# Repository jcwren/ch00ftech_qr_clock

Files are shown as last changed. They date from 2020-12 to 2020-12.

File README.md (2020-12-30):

These are the source files for the ch00ftech QR clock. I put them on GitHub
since they're somewhat hard to find on the web site. Included are links to the
original pages where they came from.

All rights remain with Michael Ciuffo. His WordPress blog at
https://ch00ftech.com has been inactive since December 15, 2017, as has his
Twitter feed.

v1.1 is the original QR clock in kit form. v2.2 is the production clock
that was available on [Tindie](https://www.tindie.com/stores/ch00ftech/)

* [Original link to v1.1 source files](https://ch00ftech.com/2012/10/27/qr-clock)
* [Original link to v2.2 source files](https://ch00ftech.com/qrclock/)
* [All QR clock related posts](https://ch00ftech.com/category/qr-clock/)

[Eagle](https://www.autodesk.com/products/eagle/overview) version 6.4 was used
for the hardware design. Eagle is at v9.6.2 at the time this README was
created. It is unknown if it can import a version that far back or not.

AVR-GCC is use to compile the firmware for the ATMega328P. It will likely
compile with more recent versions, although probably with more warnings as GCC
has improved it's detection of question expressions. It is unknown what version
was used for the original release. AVR-GCC is available
[here](https://blog.zakkemble.net/avr-gcc-builds/) for Windows, and can be
installed with HomeBrew on MacOS or apt-get (or equivalent) on Linux.

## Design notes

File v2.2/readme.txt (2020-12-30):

       _      ___   ___   __ _            _     
      | |    / _ \ / _ \ / _| |          | |    
   ___| |__ | | | | | | | |_| |_ ___  ___| |__  
  / __| '_ \| | | | | | |  _| __/ _ \/ __| '_ \ 
 | (__| | | | |_| | |_| | | | ||  __/ (__| | | |
  \___|_| |_|\___/ \___/|_|  \__\___|\___|_| |_|
                                                
QR Clock Readme v2.1 4/2/2012

By: Michael Ciuffo
ch00f@ch00ftech.com

http://ch00ftech.com/qrclock

*********************
*Package Description*
*********************

This package contains the following two folders:

--Hardware
Eagle files for schematic and PCB layout of the device along with a PNG schematic.  Digikey part numbers are included in part attributes. The symbol for D7 is backwards in the schematic.  Photodiodes should be reverse biased.

--Firmware
Firmware and Makefile for the QR clock.  Should compile with with avrdude version 5.11.1.

**********
*Versions*
**********

2.2 - Fixed a bug resulting from a misinterpretation of the QR code generation process.  After the XOR step, only the *first* zero is supposed to be removed even if more than one is there.  Modified code to only remove first zero.  This bug caused an invalid QR code with very specific inputs such as “00Y9PT0040016002”

**********
*Warnings*
**********

THIS IS NOT A TUTORIAL! These are the design files that I used to create what you see on my blog.  They are meant to be used as reference only.  If you do not understand how the project is supposed to work, do not begin working on it.  Given how haphazardly a lot of my projects are put together, in all likelihood, the designs presented herein won't actually work due to changes I made post publication.

I am a EE, not a coder.  My programming practices are questionable at best.  If you learn anything from working on this project, please don't let it be how to code like I do.

*********
*License*
*********

The contents of this package are released to you under the Creative Commons Attribution-NonCommercial 3.0 Unported license.

This means that you are free to distribute this package and edit it as you see fit.  All works based on this package must provide attribution in some form to me.  A simple link to the blog post along with a description of what you used will suffice.

You may not use this package for any commercial ventures without my consent (but I'm usually cool with it, you just have to send me an email and ask nicely).

More information here:

http://creativecommons.org/licenses/by-nc/3.0/deed.en_US

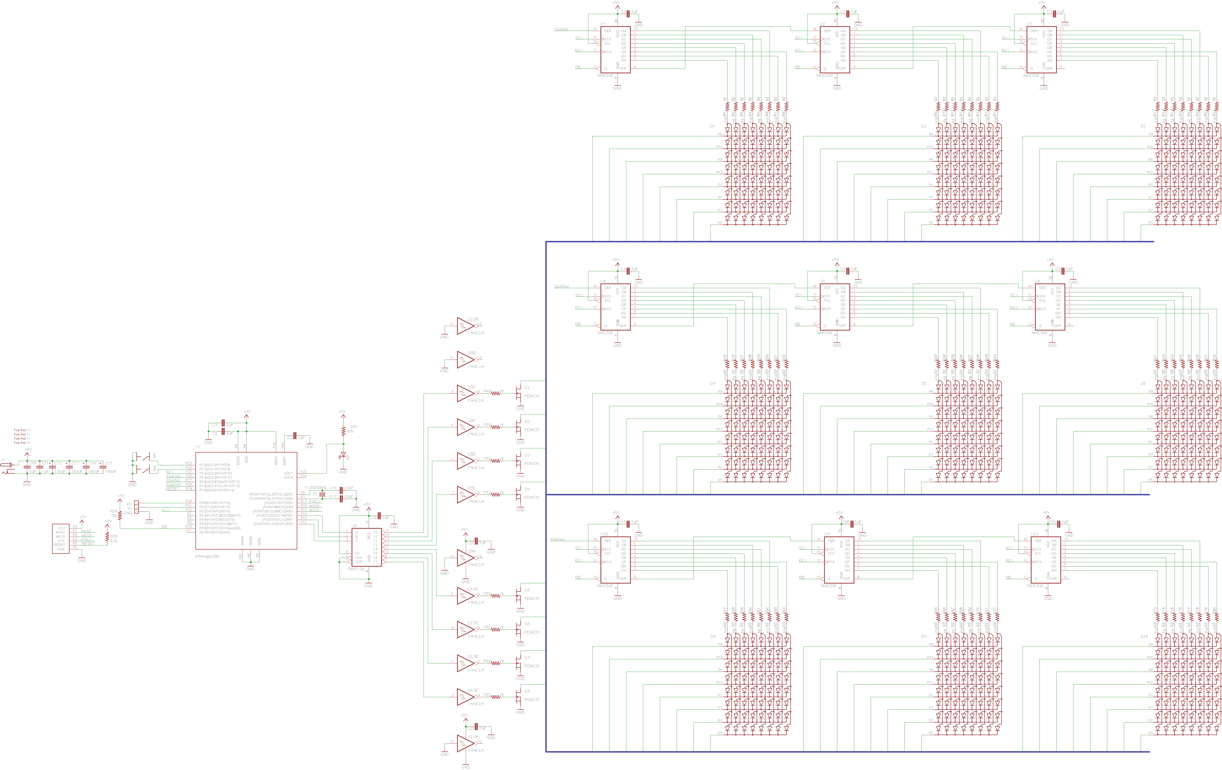
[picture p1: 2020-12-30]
v2.2/Hardware/qrclock.png

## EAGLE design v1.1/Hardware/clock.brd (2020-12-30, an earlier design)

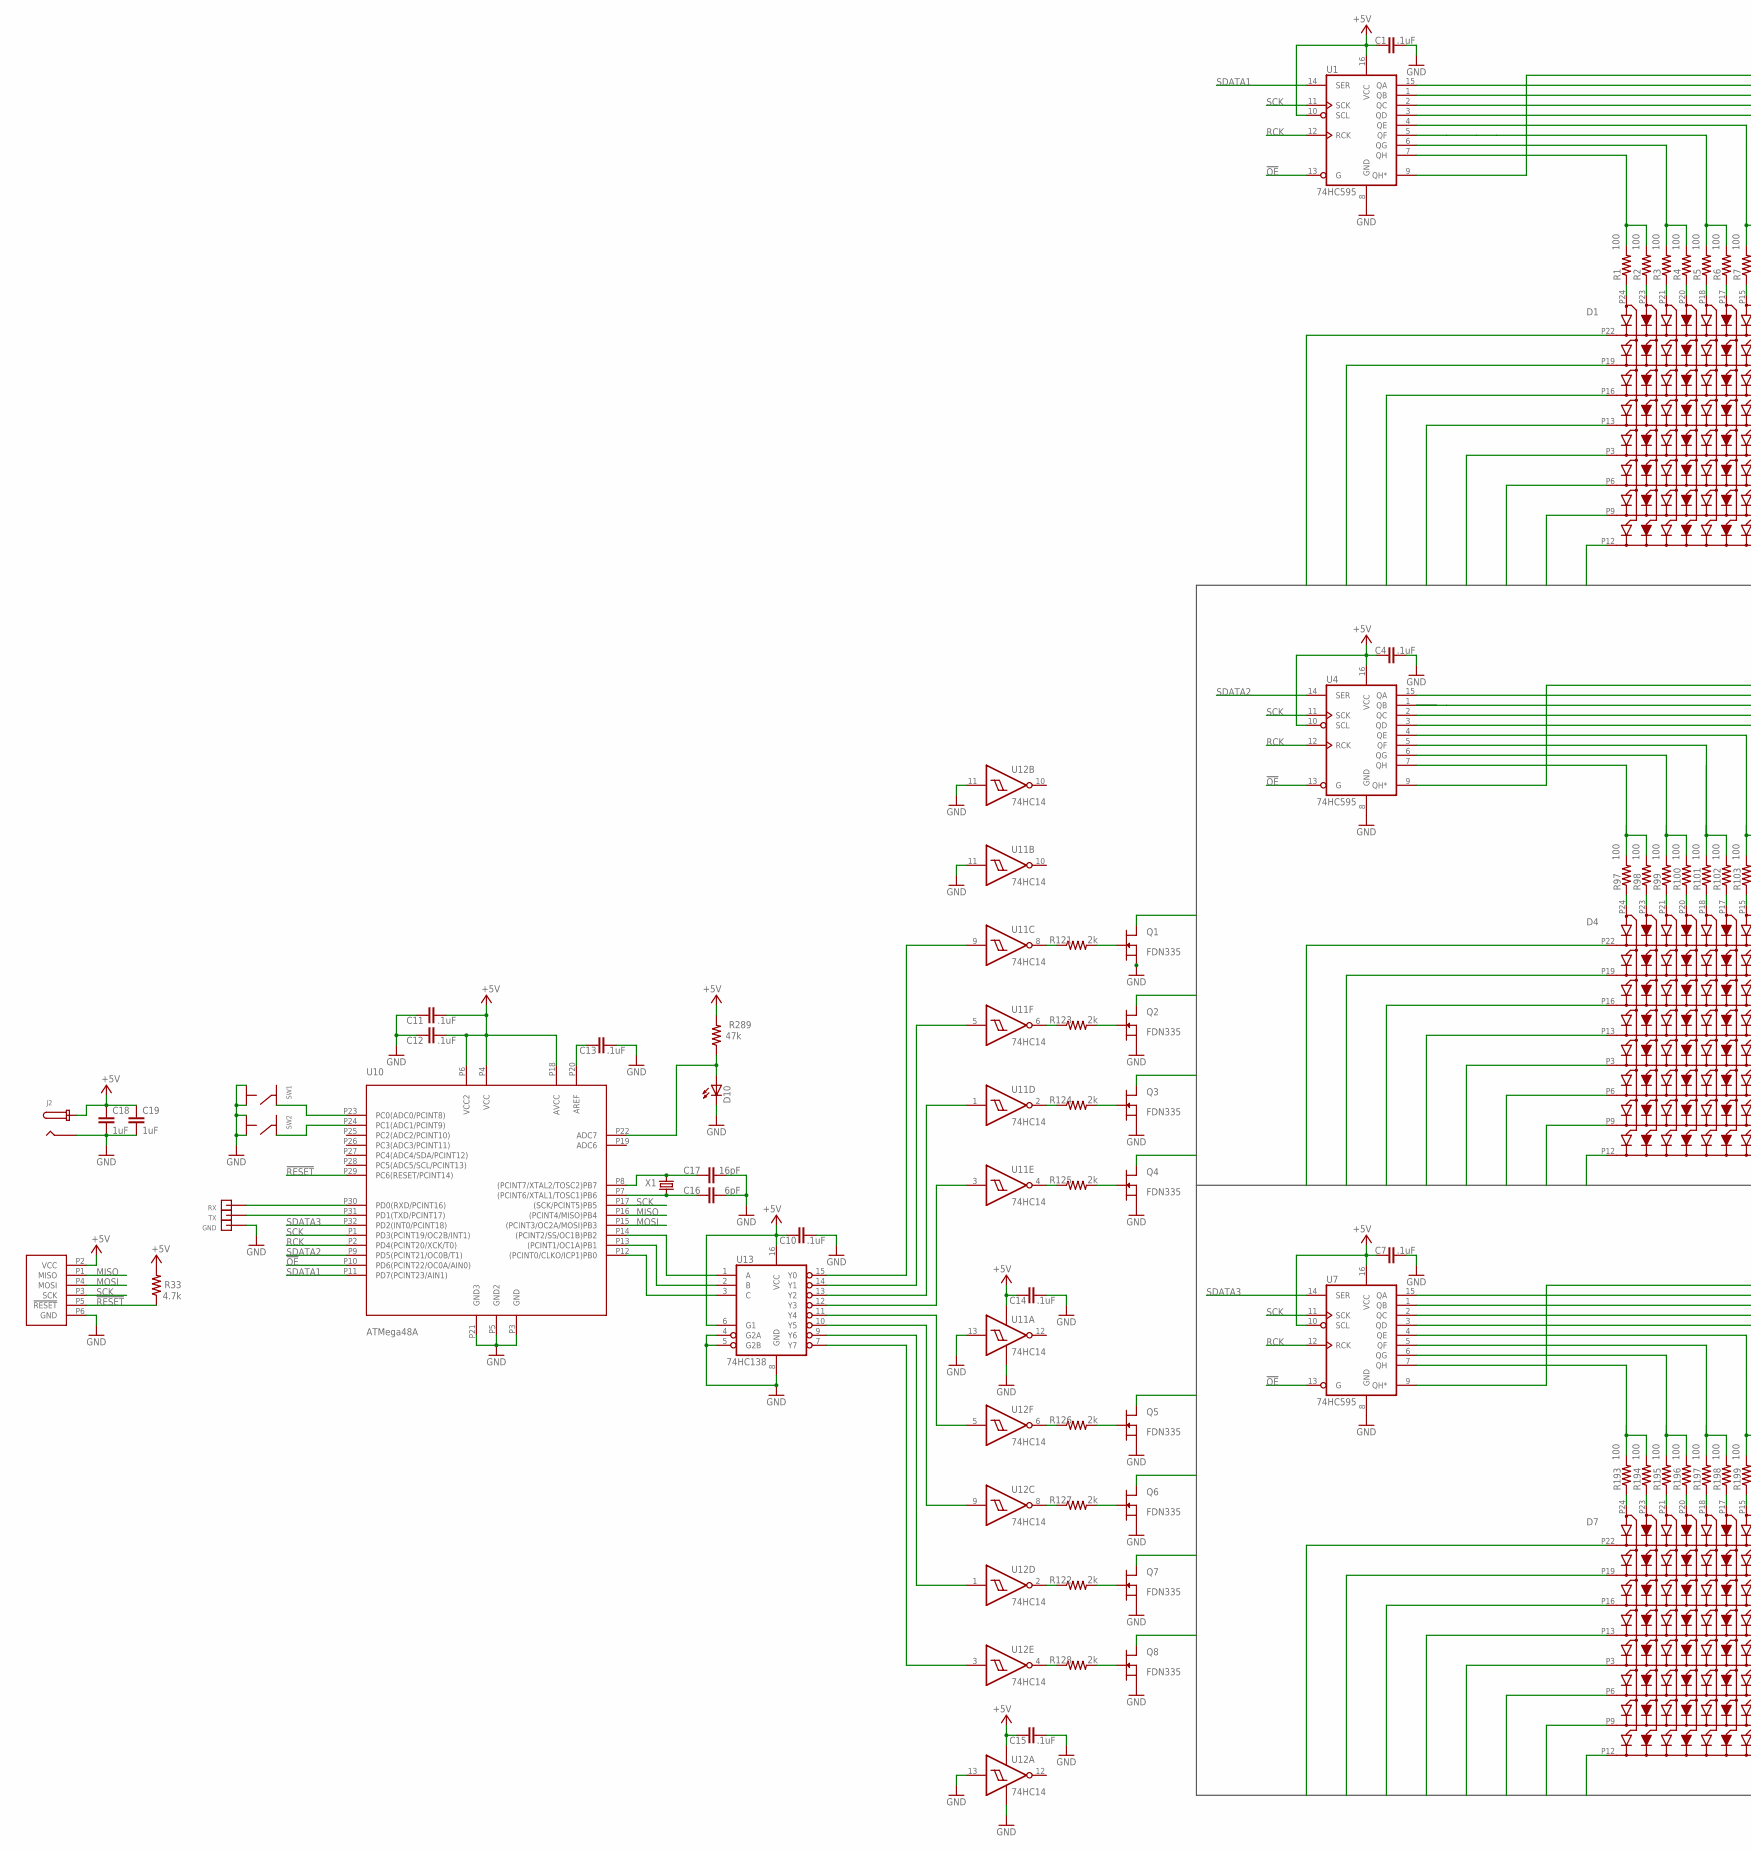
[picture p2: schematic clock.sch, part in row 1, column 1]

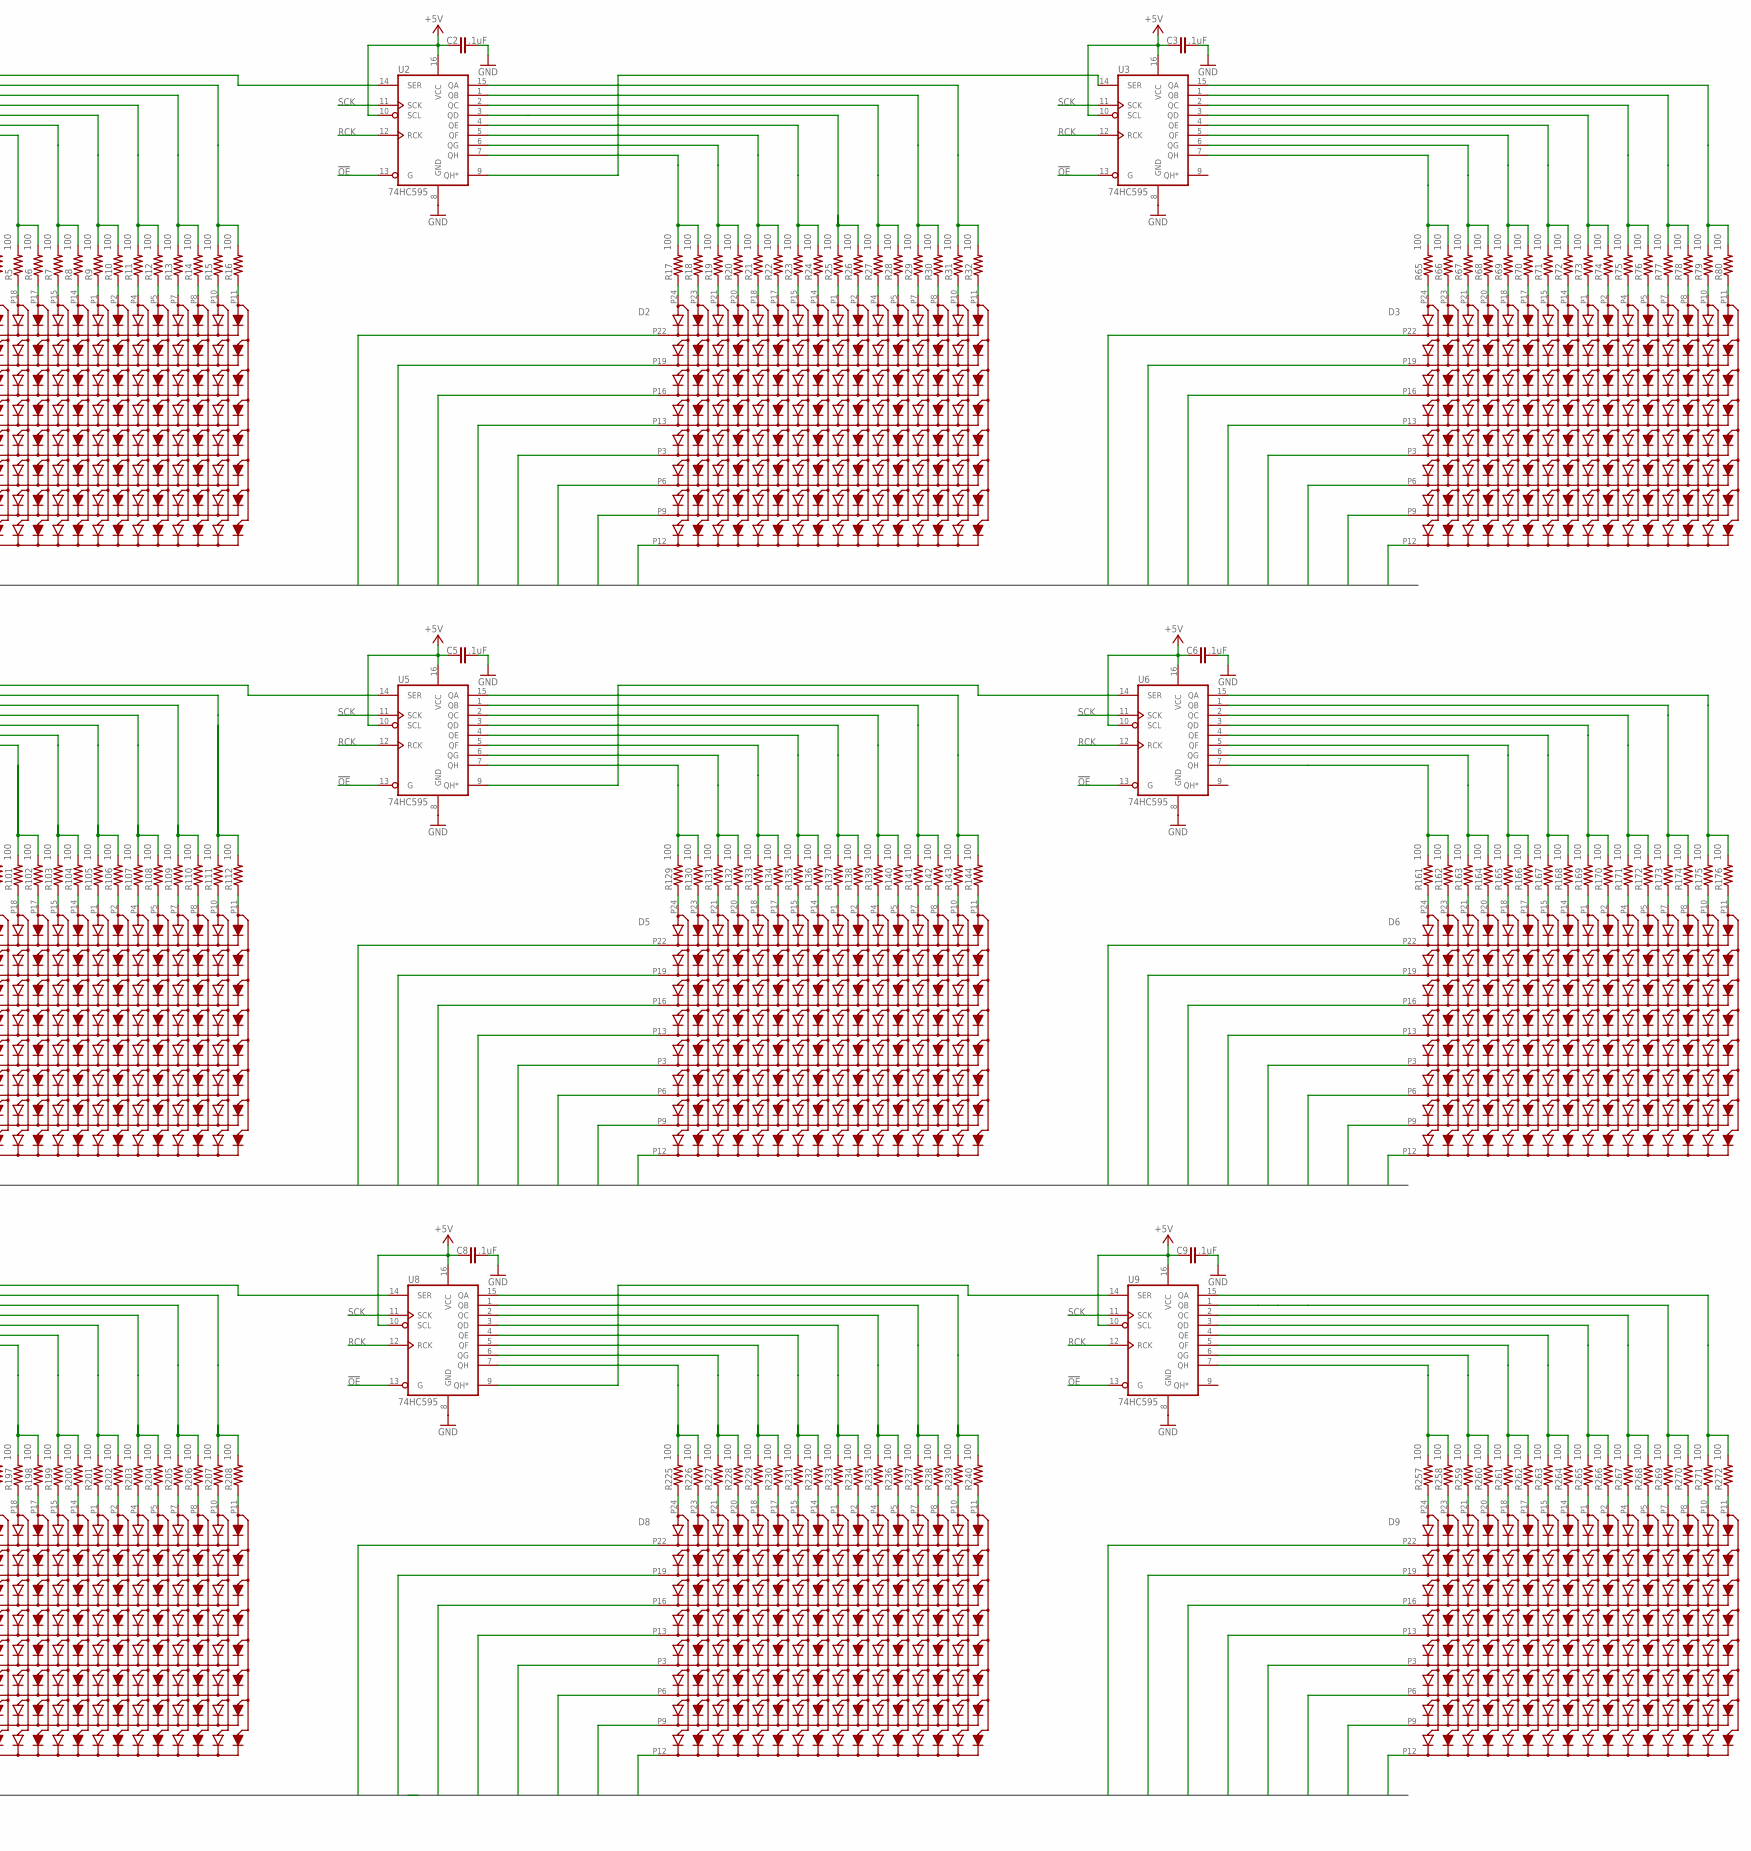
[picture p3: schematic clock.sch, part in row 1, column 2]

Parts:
C1, C2, C3, C4, C5, C6, C7, C8, C9, C10, C11, C12, C13, C14, C15: .1uF; 0603/1608METRIC
C16: 6pF; 0603/1608METRIC
C17: 16pF; 0603/1608METRIC
C18, C19: 1uF; 0603/1608METRIC
D1, D2, D3, D4, D5, D6, D7, D8, D9: BL-M12A883DUG-11"; BL-M12A883DUG-11
D10: TEPT4400; LED3MM
GND: HEADERPIN
J1: PROGHEADER-PINS; ATMEL-PROGRAMMING-HEADER
J2: DC-BARREL-JACK; PJ-037A
Q1, Q2, Q3, Q4, Q5, Q6, Q7, Q8: FDN335; SOT23
R1, R2, R3, R4, R5, R6, R7, R8, R9, R10, R11, R12, R13, R14, R15, R16, R17, R18, R19, R20, R21, R22, R23, R24, R25, R26, R27, R28, R29, R30, R31, R32, R65, R66, R67, R68, R69, R70, R71, R72, R73, R74, R75, R76, R77, R78, R79, R80, R97, R98, R99, R100, R101, R102, R103, R104, R105, R106, R107, R108, R109, R110, R111, R112, R129, R130, R131, R132, R133, R134, R135, R136, R137, R138, R139, R140, R141, R142, R143, R144, R161, R162, R163, R164, R165, R166, R167, R168, R169, R170, R171, R172, R173, R174, R175, R176, R193, R194, R195, R196, R197, R198, R199, R200, R201, R202, R203, R204, R205, R206, R207, R208, R225, R226, R227, R228, R229, R230, R231, R232, R233, R234, R235, R236, R237, R238, R239, R240, R257, R258, R259, R260, R261, R262, R263, R264, R265, R266, R267, R268, R269, R270, R271, R272: 100; 0603/1608METRIC
R33: 4.7k; 0603/1608METRIC
R121, R122, R123, R124, R125, R126, R127, R128: 2k; 0603/1608METRIC
R289: 47k; 0603/1608METRIC
RX: HEADERPIN
SW1, SW2: 4mm; FSM16JHSWITCH
TX: HEADERPIN
U1, U2, U3, U4, U5, U6, U7, U8, U9: 74HC595; SO16
U10: ATMega48A; TQFP-32
U11, U12: 74HC14; SO14
U13: 74HC138; SO16
X1: XTAL; AB38T

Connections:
!OE: U1.13 (G), U2.13 (G), U3.13 (G), U4.13 (G), U5.13 (G), U6.13 (G), U7.13 (G), U8.13 (G), U9.13 (G), U10.P10 (PD6(PCINT22/OC0A/AIN0))
!RESET: J1.P5 (!RESET), R33.P1 (1), U10.P29 (PC6(RESET/PCINT14))
+5V: C1.P1 (1), C2.P1 (1), C3.P1 (1), C4.P1 (1), C5.P1 (1), C6.P1 (1), C7.P1 (1), C8.P1 (1), C9.P1 (1), C10.P1 (1), C11.P1 (1), C12.P1 (1), C14.P1 (1), C15.P1 (1), C18.P1 (1), C19.P1 (1), J1.P2 (VCC), J2.PIN, R33.P2 (2), R289.P2 (2), U1.10 (SCL), U1.16 (VCC), U2.10 (SCL), U2.16 (VCC), U3.10 (SCL), U3.16 (VCC), U4.10 (SCL), U4.16 (VCC), U5.10 (SCL), U5.16 (VCC), U6.10 (SCL), U6.16 (VCC), U7.10 (SCL), U7.16 (VCC), U8.10 (SCL), U8.16 (VCC), U9.10 (SCL), U9.16 (VCC), U10.P4 (VCC), U10.P6 (VCC2), U10.P18 (AVCC), U11.14 (VCC), U12.14 (VCC), U13.6 (G1), U13.16 (VCC)
GND: C1.P2 (2), C2.P2 (2), C3.P2 (2), C4.P2 (2), C5.P2 (2), C6.P2 (2), C7.P2 (2), C8.P2 (2), C9.P2 (2), C10.P2 (2), C11.P2 (2), C12.P2 (2), C13.P2 (2), C14.P2 (2), C15.P2 (2), C16.P2 (2), C17.P2 (2), C18.P2 (2), C19.P2 (2), D10.K (C), GND.P$1, J1.P6 (GND), J2.BARREL, Q1.2 (S), Q2.2 (S), Q3.2 (S), Q4.2 (S), Q5.2 (S), Q6.2 (S), Q7.2 (S), Q8.2 (S), SW1.P3, SW1.P4, SW2.P3, SW2.P4, U1.8 (GND), U2.8 (GND), U3.8 (GND), U4.8 (GND), U5.8 (GND), U6.8 (GND), U7.8 (GND), U8.8 (GND), U9.8 (GND), U10.P3 (GND), U10.P5 (GND2), U10.P21 (GND3), U11.7 (GND), U11.11 (I), U11.13 (I), U12.7 (GND), U12.11 (I), U12.13 (I), U13.4 (G2A), U13.5 (G2B), U13.8 (GND)
MISO: J1.P1 (MISO), U10.P16 ((PCINT4/MISO)PB4)
MOSI: J1.P4 (MOSI), U10.P15 ((PCINT3/OC2A/MOSI)PB3)
unnamed: D1.P24 (C1G), R1.P1 (1)
unnamed: D1.P23 (C1R), R2.P1 (1)
unnamed: D1.P21 (C2G), R3.P1 (1)
unnamed: D1.P20 (C2R), R4.P1 (1)
unnamed: D1.P18 (C3G), R5.P1 (1)
unnamed: D1.P17 (C3R), R6.P1 (1)
unnamed: D1.P15 (C4G), R7.P1 (1)
unnamed: D1.P14 (C4R), R8.P1 (1)
unnamed: D1.P1 (C5G), R9.P1 (1)
unnamed: D1.P2 (C5R), R10.P1 (1)
unnamed: D1.P4 (C6G), R11.P1 (1)
unnamed: D1.P5 (C6R), R12.P1 (1)
unnamed: D1.P7 (C7G), R13.P1 (1)
unnamed: D1.P8 (C7R), R14.P1 (1)
unnamed: D1.P10 (C8G), R15.P1 (1)
unnamed: D1.P11 (C8R), R16.P1 (1)
unnamed: U11.9 (I), U13.15 (Y0)
unnamed: D2.P24 (C1G), R17.P1 (1)
unnamed: D2.P23 (C1R), R18.P1 (1)
unnamed: D2.P21 (C2G), R19.P1 (1)
unnamed: D2.P20 (C2R), R20.P1 (1)
unnamed: D2.P18 (C3G), R21.P1 (1)
unnamed: D2.P17 (C3R), R22.P1 (1)
unnamed: D2.P15 (C4G), R23.P1 (1)
unnamed: D2.P14 (C4R), R24.P1 (1)
unnamed: D2.P1 (C5G), R25.P1 (1)
unnamed: D2.P2 (C5R), R26.P1 (1)
unnamed: D2.P4 (C6G), R27.P1 (1)
unnamed: D2.P5 (C6R), R28.P1 (1)
unnamed: D2.P7 (C7G), R29.P1 (1)
unnamed: D2.P8 (C7R), R30.P1 (1)
unnamed: D2.P10 (C8G), R31.P1 (1)
unnamed: R124.P1 (1), U11.2 (O)
unnamed: R123.P1 (1), U11.6 (O)
unnamed: R121.P1 (1), U11.8 (O)
unnamed: R125.P1 (1), U11.4 (O)
unnamed: R128.P1 (1), U12.4 (O)
unnamed: R122.P1 (1), U12.2 (O)
unnamed: R127.P1 (1), U12.8 (O)
unnamed: R126.P1 (1), U12.6 (O)
unnamed: C16.P1 (1), U10.P7 ((PCINT6/XTAL1/TOSC1)PB6), X1.P$1 (1)
unnamed: R3.P2 (2), R4.P2 (2), U1.6 (QG)
unnamed: TX.P$1, U10.P31 (PD1(TXD/PCINT17))
unnamed: C17.P1 (1), U10.P8 ((PCINT7/XTAL2/TOSC2)PB7), X1.P$2 (2)
unnamed: RX.P$1, U10.P30 (PD0(RXD/PCINT16))
unnamed: Q3.1 (G), R124.P2 (2)
unnamed: SW2.P2, U10.P24 (PC1(ADC1/PCINT9))
unnamed: SW1.P2, U10.P23 (PC0(ADC0/PCINT8))
unnamed: R1.P2 (2), R2.P2 (2), U1.7 (QH)
unnamed: Q1.1 (G), R121.P2 (2)
unnamed: R5.P2 (2), R6.P2 (2), U1.5 (QF)
unnamed: R7.P2 (2), R8.P2 (2), U1.4 (QE)
unnamed: R9.P2 (2), R10.P2 (2), U1.3 (QD)
unnamed: R11.P2 (2), R12.P2 (2), U1.2 (QC)
unnamed: R13.P2 (2), R14.P2 (2), U1.1 (QB)
unnamed: R15.P2 (2), R16.P2 (2), U1.15 (QA)
unnamed: U11.5 (I), U13.14 (Y1)
unnamed: U4.9 (QH*), U5.14 (SER)
unnamed: U5.9 (QH*), U6.14 (SER)
unnamed: U11.1 (I), U13.13 (Y2)
unnamed: U1.9 (QH*), U2.14 (SER)
unnamed: U2.9 (QH*), U3.14 (SER)
unnamed: D2.P11 (C8R), R32.P1 (1)
unnamed: R25.P2 (2), R26.P2 (2), U2.3 (QD)
unnamed: R23.P2 (2), R24.P2 (2), U2.4 (QE)
unnamed: R19.P2 (2), R20.P2 (2), U2.6 (QG)
unnamed: R17.P2 (2), R18.P2 (2), U2.7 (QH)
unnamed: R21.P2 (2), R22.P2 (2), U2.5 (QF)
unnamed: R27.P2 (2), R28.P2 (2), U2.2 (QC)
unnamed: R29.P2 (2), R30.P2 (2), U2.1 (QB)
unnamed: R31.P2 (2), R32.P2 (2), U2.15 (QA)
unnamed: U7.9 (QH*), U8.14 (SER)
unnamed: U8.9 (QH*), U9.14 (SER)
unnamed: U11.3 (I), U13.12 (Y3)
unnamed: U12.5 (I), U13.11 (Y4)
unnamed: U12.9 (I), U13.10 (Y5)
unnamed: U12.1 (I), U13.9 (Y6)
unnamed: U12.3 (I), U13.7 (Y7)
unnamed: D10.A, R289.P1 (1), U10.P22 (ADC7)
unnamed: D3.P24 (C1G), R65.P1 (1)
unnamed: D3.P23 (C1R), R66.P1 (1)
unnamed: D3.P21 (C2G), R67.P1 (1)
unnamed: D3.P20 (C2R), R68.P1 (1)
unnamed: D3.P18 (C3G), R69.P1 (1)
unnamed: D3.P17 (C3R), R70.P1 (1)
unnamed: D3.P15 (C4G), R71.P1 (1)
unnamed: D3.P14 (C4R), R72.P1 (1)
unnamed: D3.P1 (C5G), R73.P1 (1)
unnamed: D3.P2 (C5R), R74.P1 (1)
unnamed: D3.P4 (C6G), R75.P1 (1)
unnamed: D3.P5 (C6R), R76.P1 (1)
unnamed: D3.P7 (C7G), R77.P1 (1)
unnamed: D3.P8 (C7R), R78.P1 (1)
unnamed: D3.P10 (C8G), R79.P1 (1)
unnamed: D3.P11 (C8R), R80.P1 (1)
unnamed: R65.P2 (2), R66.P2 (2), U3.7 (QH)
unnamed: R67.P2 (2), R68.P2 (2), U3.6 (QG)
unnamed: R69.P2 (2), R70.P2 (2), U3.5 (QF)
unnamed: R71.P2 (2), R72.P2 (2), U3.4 (QE)
unnamed: R73.P2 (2), R74.P2 (2), U3.3 (QD)
unnamed: R75.P2 (2), R76.P2 (2), U3.2 (QC)
unnamed: R77.P2 (2), R78.P2 (2), U3.1 (QB)
unnamed: R79.P2 (2), R80.P2 (2), U3.15 (QA)
unnamed: U10.P12 ((PCINT0/CLKO/ICP1)PB0), U13.3 (C)
unnamed: U10.P13 ((PCINT1/OC1A)PB1), U13.2 (B)
unnamed: U10.P14 ((PCINT2/SS/OC1B)PB2), U13.1 (A)
unnamed: C13.P1 (1), U10.P20 (AREF)
unnamed: D4.P24 (C1G), R97.P1 (1)
unnamed: D4.P23 (C1R), R98.P1 (1)
unnamed: D4.P21 (C2G), R99.P1 (1)
unnamed: D4.P20 (C2R), R100.P1 (1)
unnamed: D4.P18 (C3G), R101.P1 (1)
unnamed: D4.P17 (C3R), R102.P1 (1)
unnamed: D4.P15 (C4G), R103.P1 (1)
unnamed: D4.P14 (C4R), R104.P1 (1)
unnamed: D4.P1 (C5G), R105.P1 (1)
unnamed: D4.P2 (C5R), R106.P1 (1)
unnamed: D4.P4 (C6G), R107.P1 (1)
unnamed: D4.P5 (C6R), R108.P1 (1)
unnamed: D4.P7 (C7G), R109.P1 (1)
unnamed: D4.P8 (C7R), R110.P1 (1)
unnamed: D4.P10 (C8G), R111.P1 (1)
unnamed: D4.P11 (C8R), R112.P1 (1)
unnamed: R109.P2 (2), R110.P2 (2), U4.1 (QB)
unnamed: R97.P2 (2), R98.P2 (2), U4.7 (QH)
unnamed: R99.P2 (2), R100.P2 (2), U4.6 (QG)
unnamed: R101.P2 (2), R102.P2 (2), U4.5 (QF)
unnamed: R103.P2 (2), R104.P2 (2), U4.4 (QE)
unnamed: R105.P2 (2), R106.P2 (2), U4.3 (QD)
unnamed: R107.P2 (2), R108.P2 (2), U4.2 (QC)
unnamed: R111.P2 (2), R112.P2 (2), U4.15 (QA)
unnamed: Q7.1 (G), R122.P2 (2)
unnamed: Q2.1 (G), R123.P2 (2)
unnamed: Q4.1 (G), R125.P2 (2)
unnamed: Q5.1 (G), R126.P2 (2)
unnamed: Q6.1 (G), R127.P2 (2)
unnamed: Q8.1 (G), R128.P2 (2)
unnamed: D5.P24 (C1G), R129.P1 (1)
unnamed: D5.P23 (C1R), R130.P1 (1)
unnamed: D5.P21 (C2G), R131.P1 (1)
unnamed: D5.P20 (C2R), R132.P1 (1)
unnamed: D5.P18 (C3G), R133.P1 (1)
unnamed: D5.P17 (C3R), R134.P1 (1)
unnamed: D5.P15 (C4G), R135.P1 (1)
unnamed: D5.P14 (C4R), R136.P1 (1)
unnamed: D5.P1 (C5G), R137.P1 (1)
unnamed: D5.P2 (C5R), R138.P1 (1)
unnamed: D5.P4 (C6G), R139.P1 (1)
unnamed: D5.P5 (C6R), R140.P1 (1)
unnamed: D5.P7 (C7G), R141.P1 (1)
unnamed: D5.P8 (C7R), R142.P1 (1)
unnamed: D5.P10 (C8G), R143.P1 (1)
unnamed: D5.P11 (C8R), R144.P1 (1)
unnamed: R129.P2 (2), R130.P2 (2), U5.7 (QH)
unnamed: R131.P2 (2), R132.P2 (2), U5.6 (QG)
unnamed: R133.P2 (2), R134.P2 (2), U5.5 (QF)
unnamed: R135.P2 (2), R136.P2 (2), U5.4 (QE)
unnamed: R137.P2 (2), R138.P2 (2), U5.3 (QD)
unnamed: R139.P2 (2), R140.P2 (2), U5.2 (QC)
unnamed: R141.P2 (2), R142.P2 (2), U5.1 (QB)
unnamed: R143.P2 (2), R144.P2 (2), U5.15 (QA)
unnamed: D6.P24 (C1G), R161.P1 (1)
unnamed: D6.P23 (C1R), R162.P1 (1)
unnamed: D6.P21 (C2G), R163.P1 (1)
unnamed: D6.P20 (C2R), R164.P1 (1)
unnamed: D6.P18 (C3G), R165.P1 (1)
unnamed: D6.P17 (C3R), R166.P1 (1)
unnamed: D6.P15 (C4G), R167.P1 (1)
unnamed: D6.P14 (C4R), R168.P1 (1)
unnamed: D6.P1 (C5G), R169.P1 (1)
unnamed: D6.P2 (C5R), R170.P1 (1)
unnamed: D6.P4 (C6G), R171.P1 (1)
unnamed: D6.P5 (C6R), R172.P1 (1)
unnamed: D6.P7 (C7G), R173.P1 (1)
unnamed: D6.P8 (C7R), R174.P1 (1)
unnamed: D6.P10 (C8G), R175.P1 (1)
unnamed: D6.P11 (C8R), R176.P1 (1)
unnamed: R161.P2 (2), R162.P2 (2), U6.7 (QH)
unnamed: R163.P2 (2), R164.P2 (2), U6.6 (QG)
unnamed: R165.P2 (2), R166.P2 (2), U6.5 (QF)
unnamed: R167.P2 (2), R168.P2 (2), U6.4 (QE)
unnamed: R169.P2 (2), R170.P2 (2), U6.3 (QD)
unnamed: R171.P2 (2), R172.P2 (2), U6.2 (QC)
unnamed: R173.P2 (2), R174.P2 (2), U6.1 (QB)
unnamed: R175.P2 (2), R176.P2 (2), U6.15 (QA)
unnamed: D7.P24 (C1G), R193.P1 (1)
unnamed: D7.P23 (C1R), R194.P1 (1)
unnamed: D7.P21 (C2G), R195.P1 (1)
unnamed: D7.P20 (C2R), R196.P1 (1)
unnamed: D7.P18 (C3G), R197.P1 (1)
unnamed: D7.P17 (C3R), R198.P1 (1)
unnamed: D7.P15 (C4G), R199.P1 (1)
unnamed: D7.P14 (C4R), R200.P1 (1)
unnamed: D7.P1 (C5G), R201.P1 (1)
unnamed: D7.P2 (C5R), R202.P1 (1)
unnamed: D7.P4 (C6G), R203.P1 (1)
unnamed: D7.P5 (C6R), R204.P1 (1)
unnamed: D7.P7 (C7G), R205.P1 (1)
unnamed: D7.P8 (C7R), R206.P1 (1)
unnamed: D7.P10 (C8G), R207.P1 (1)
unnamed: D7.P11 (C8R), R208.P1 (1)
unnamed: R193.P2 (2), R194.P2 (2), U7.7 (QH)
unnamed: R195.P2 (2), R196.P2 (2), U7.6 (QG)
unnamed: R197.P2 (2), R198.P2 (2), U7.5 (QF)
unnamed: R199.P2 (2), R200.P2 (2), U7.4 (QE)
unnamed: R201.P2 (2), R202.P2 (2), U7.3 (QD)
unnamed: R203.P2 (2), R204.P2 (2), U7.2 (QC)
unnamed: R205.P2 (2), R206.P2 (2), U7.1 (QB)
unnamed: R207.P2 (2), R208.P2 (2), U7.15 (QA)
unnamed: D8.P24 (C1G), R225.P1 (1)
unnamed: D8.P23 (C1R), R226.P1 (1)
unnamed: D8.P21 (C2G), R227.P1 (1)
unnamed: D8.P20 (C2R), R228.P1 (1)
unnamed: D8.P18 (C3G), R229.P1 (1)
unnamed: D8.P17 (C3R), R230.P1 (1)
unnamed: D8.P15 (C4G), R231.P1 (1)
unnamed: D8.P14 (C4R), R232.P1 (1)
unnamed: D8.P1 (C5G), R233.P1 (1)
unnamed: D8.P2 (C5R), R234.P1 (1)
unnamed: D8.P4 (C6G), R235.P1 (1)
unnamed: D8.P5 (C6R), R236.P1 (1)
unnamed: D8.P7 (C7G), R237.P1 (1)
unnamed: D8.P8 (C7R), R238.P1 (1)
unnamed: D8.P10 (C8G), R239.P1 (1)
unnamed: D8.P11 (C8R), R240.P1 (1)
unnamed: R225.P2 (2), R226.P2 (2), U8.7 (QH)
unnamed: R227.P2 (2), R228.P2 (2), U8.6 (QG)
unnamed: R229.P2 (2), R230.P2 (2), U8.5 (QF)
unnamed: R231.P2 (2), R232.P2 (2), U8.4 (QE)
unnamed: R233.P2 (2), R234.P2 (2), U8.3 (QD)
unnamed: R235.P2 (2), R236.P2 (2), U8.2 (QC)
unnamed: R237.P2 (2), R238.P2 (2), U8.1 (QB)
unnamed: R239.P2 (2), R240.P2 (2), U8.15 (QA)
unnamed: D9.P24 (C1G), R257.P1 (1)
unnamed: D9.P23 (C1R), R258.P1 (1)
unnamed: D9.P21 (C2G), R259.P1 (1)
unnamed: D9.P20 (C2R), R260.P1 (1)
unnamed: D9.P18 (C3G), R261.P1 (1)
unnamed: D9.P17 (C3R), R262.P1 (1)
unnamed: D9.P15 (C4G), R263.P1 (1)
unnamed: D9.P14 (C4R), R264.P1 (1)
unnamed: D9.P1 (C5G), R265.P1 (1)
unnamed: D9.P2 (C5R), R266.P1 (1)
unnamed: D9.P4 (C6G), R267.P1 (1)
unnamed: D9.P5 (C6R), R268.P1 (1)
unnamed: D9.P7 (C7G), R269.P1 (1)
unnamed: D9.P8 (C7R), R270.P1 (1)
unnamed: D9.P10 (C8G), R271.P1 (1)
unnamed: D9.P11 (C8R), R272.P1 (1)
unnamed: R269.P2 (2), R270.P2 (2), U9.1 (QB)
unnamed: R257.P2 (2), R258.P2 (2), U9.7 (QH)
unnamed: R259.P2 (2), R260.P2 (2), U9.6 (QG)
unnamed: R261.P2 (2), R262.P2 (2), U9.5 (QF)
unnamed: R263.P2 (2), R264.P2 (2), U9.4 (QE)
unnamed: R265.P2 (2), R266.P2 (2), U9.3 (QD)
unnamed: R267.P2 (2), R268.P2 (2), U9.2 (QC)
unnamed: R271.P2 (2), R272.P2 (2), U9.15 (QA)
RCK: U1.12 (RCK), U2.12 (RCK), U3.12 (RCK), U4.12 (RCK), U5.12 (RCK), U6.12 (RCK), U7.12 (RCK), U8.12 (RCK), U9.12 (RCK), U10.P2 (PD4(PCINT20/XCK/T0))
ROW0: D1.P22 (R1), D2.P22 (R1), D3.P22 (R1), D4.P22 (R1), D5.P22 (R1), D6.P22 (R1), D7.P22 (R1), D8.P22 (R1), D9.P22 (R1), Q1.3 (D)
ROW1: D1.P19 (R2), D2.P19 (R2), D3.P19 (R2), D4.P19 (R2), D5.P19 (R2), D6.P19 (R2), D7.P19 (R2), D8.P19 (R2), D9.P19 (R2), Q2.3 (D)
ROW2: D1.P16 (R3), D2.P16 (R3), D3.P16 (R3), D4.P16 (R3), D5.P16 (R3), D6.P16 (R3), D7.P16 (R3), D8.P16 (R3), D9.P16 (R3), Q3.3 (D)
ROW3: D1.P13 (R4), D2.P13 (R4), D3.P13 (R4), D4.P13 (R4), D5.P13 (R4), D6.P13 (R4), D7.P13 (R4), D8.P13 (R4), D9.P13 (R4), Q4.3 (D)
ROW4: D1.P3 (R5), D2.P3 (R5), D3.P3 (R5), D4.P3 (R5), D5.P3 (R5), D6.P3 (R5), D7.P3 (R5), D8.P3 (R5), D9.P3 (R5), Q5.3 (D)
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

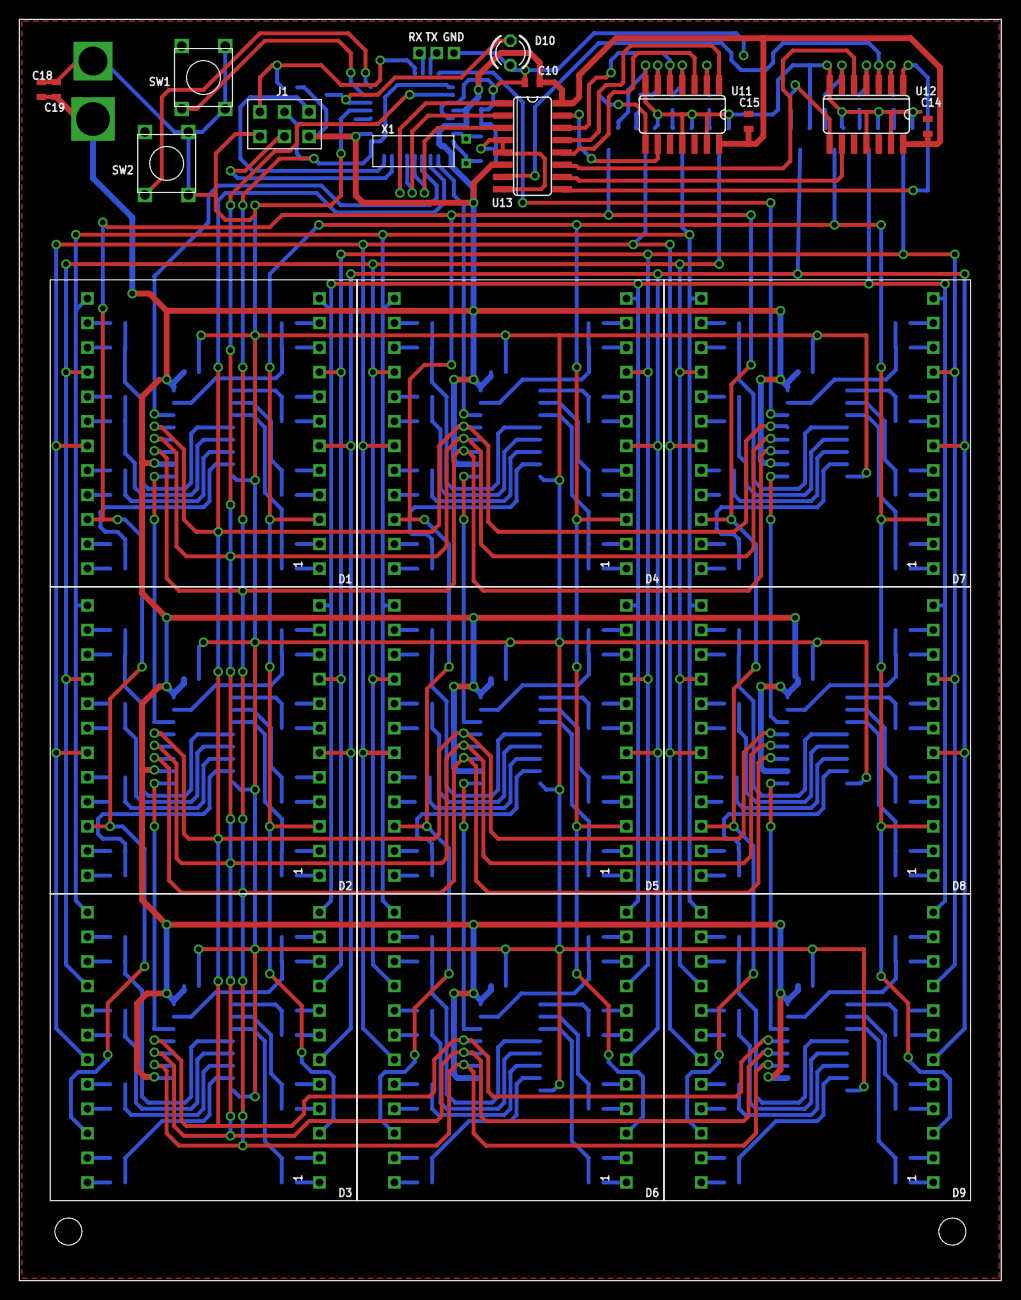
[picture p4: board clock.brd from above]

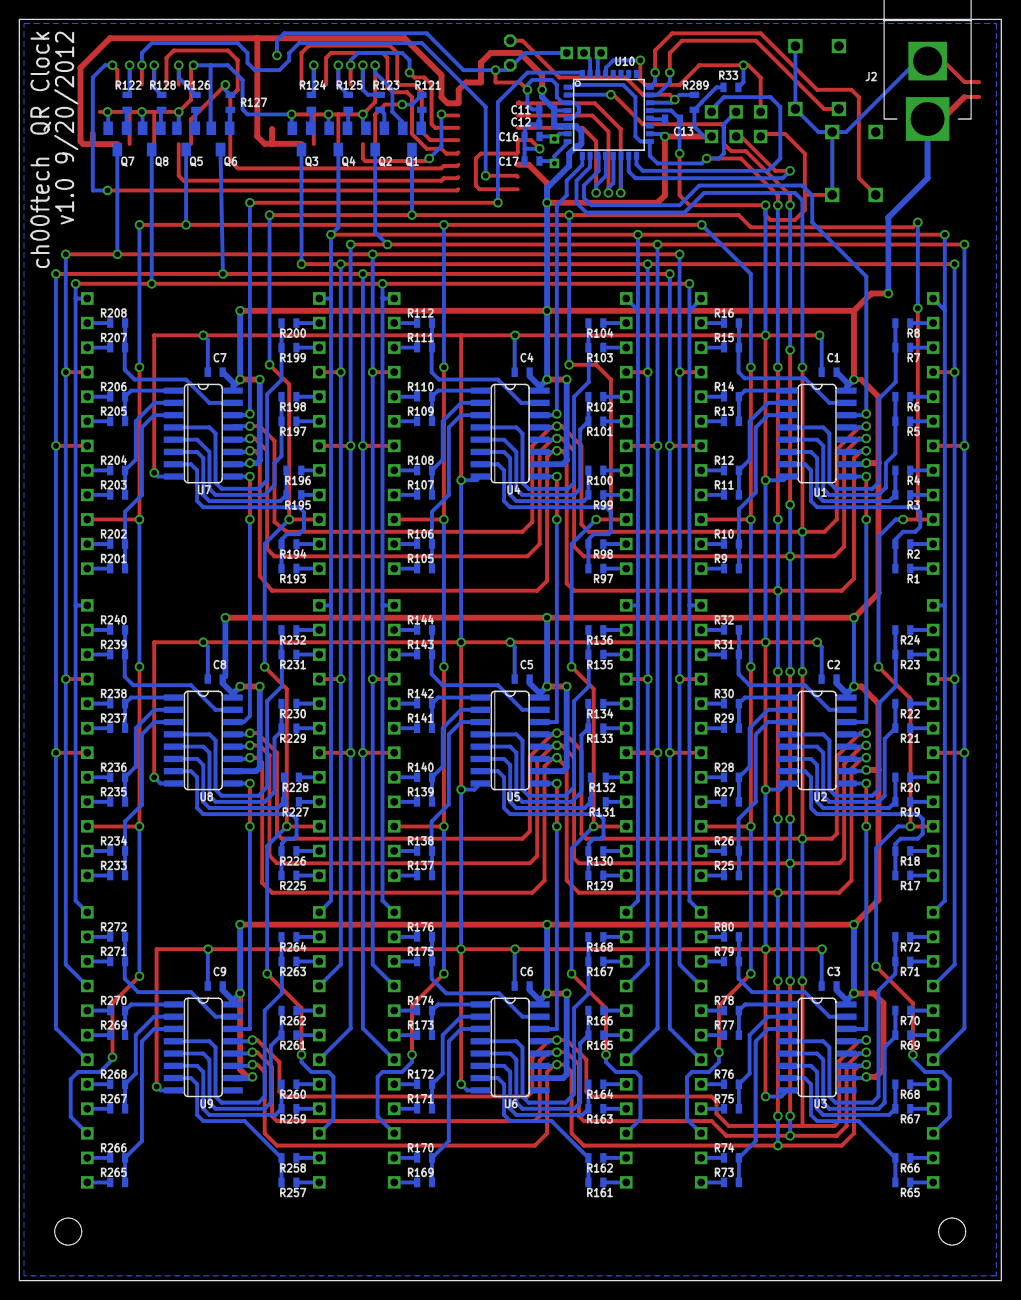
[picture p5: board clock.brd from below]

Board: 2 copper layers, 101.6 x 130.5 mm, 212 parts (187 on the bottom side), 276 nets.

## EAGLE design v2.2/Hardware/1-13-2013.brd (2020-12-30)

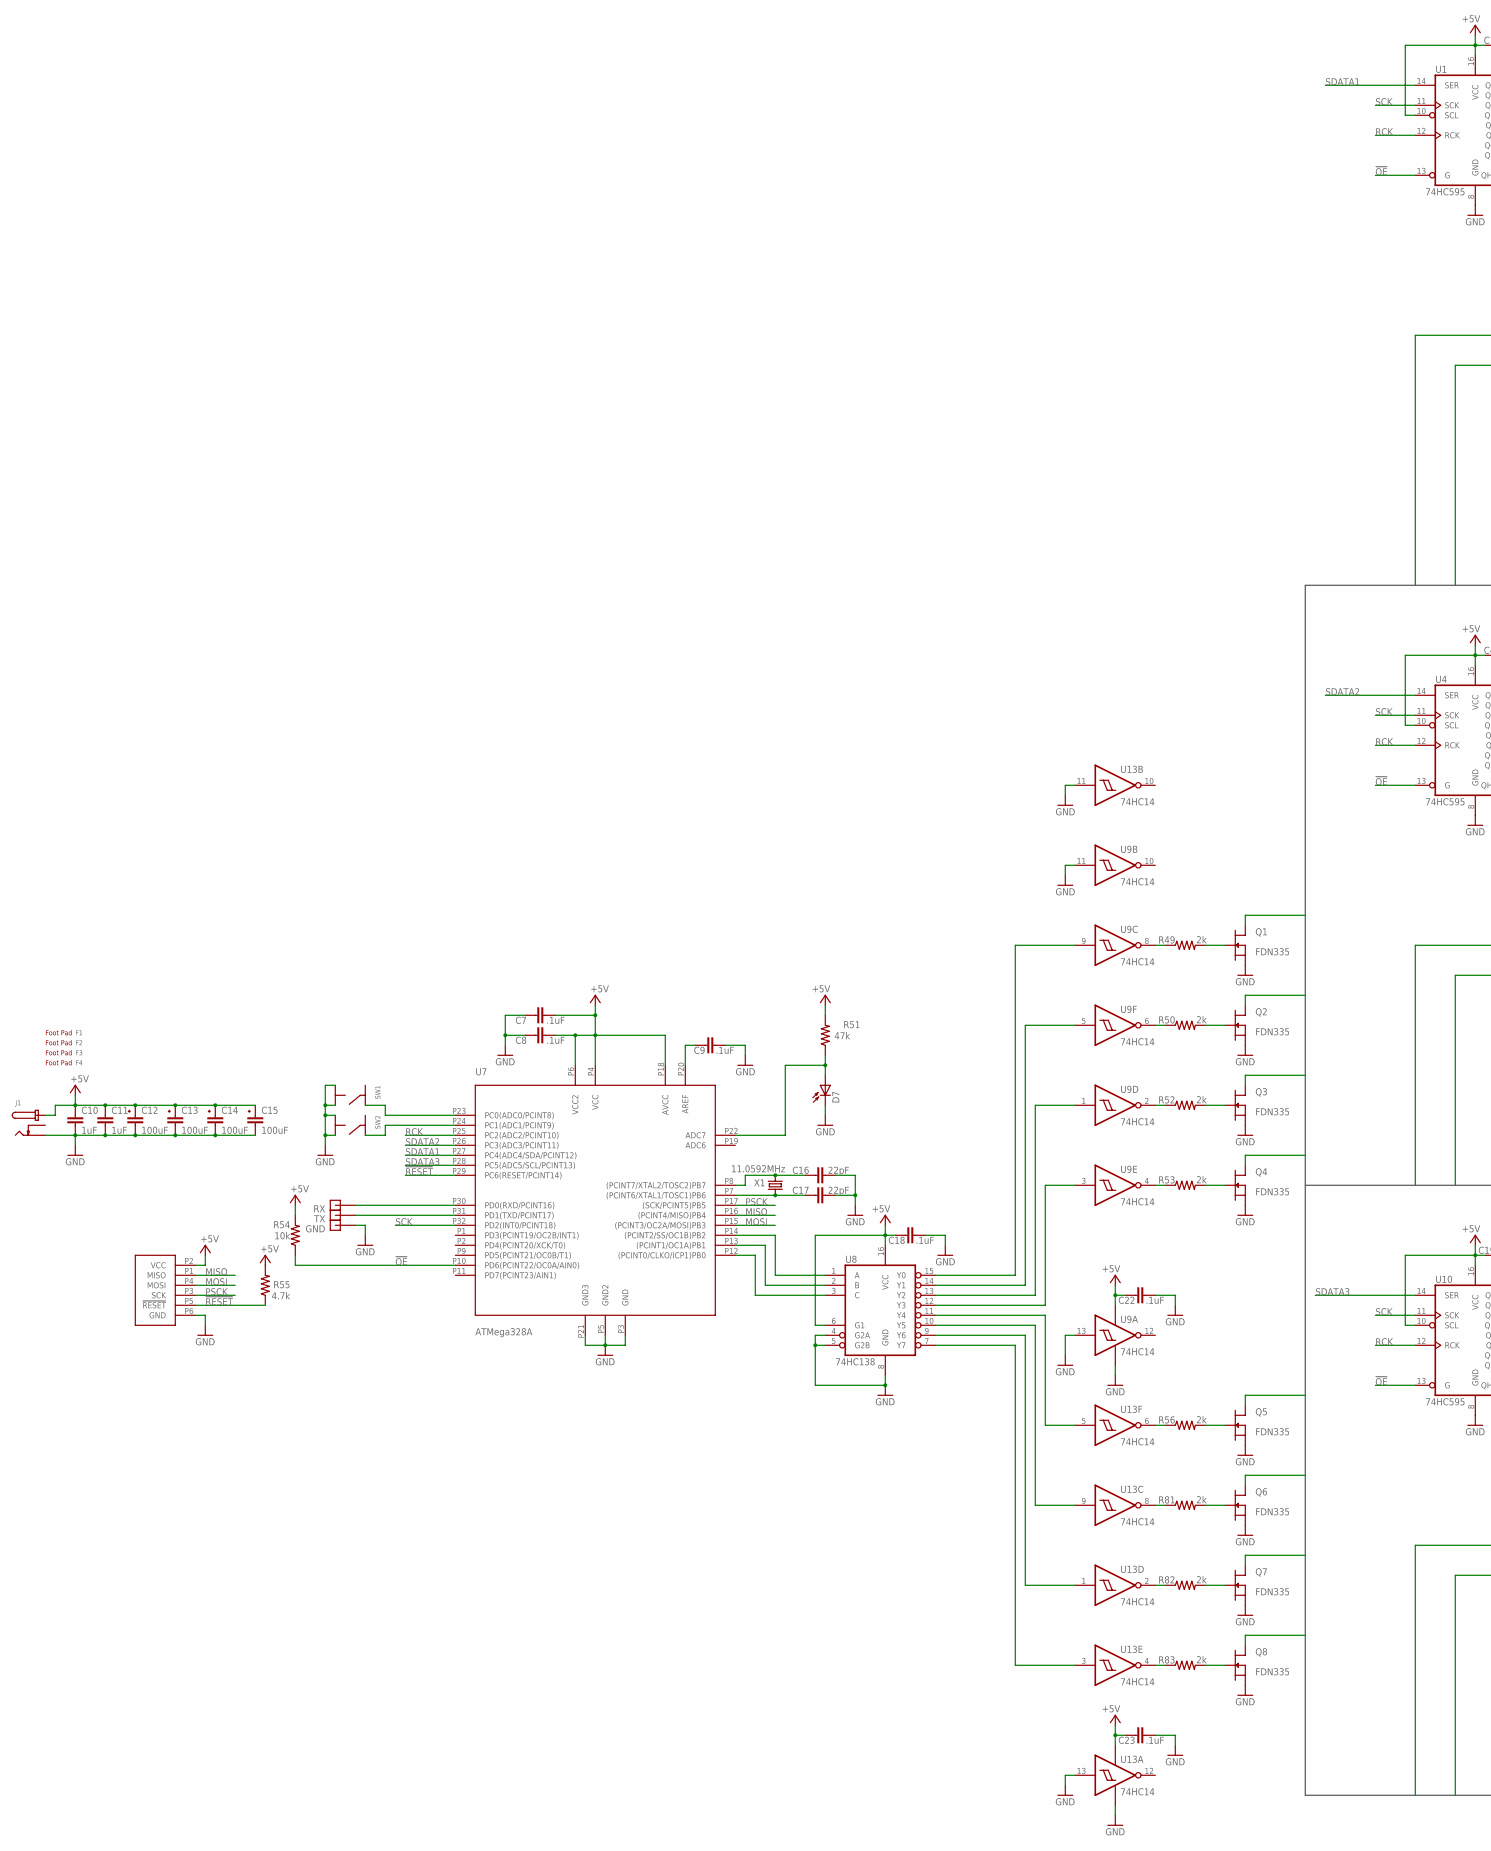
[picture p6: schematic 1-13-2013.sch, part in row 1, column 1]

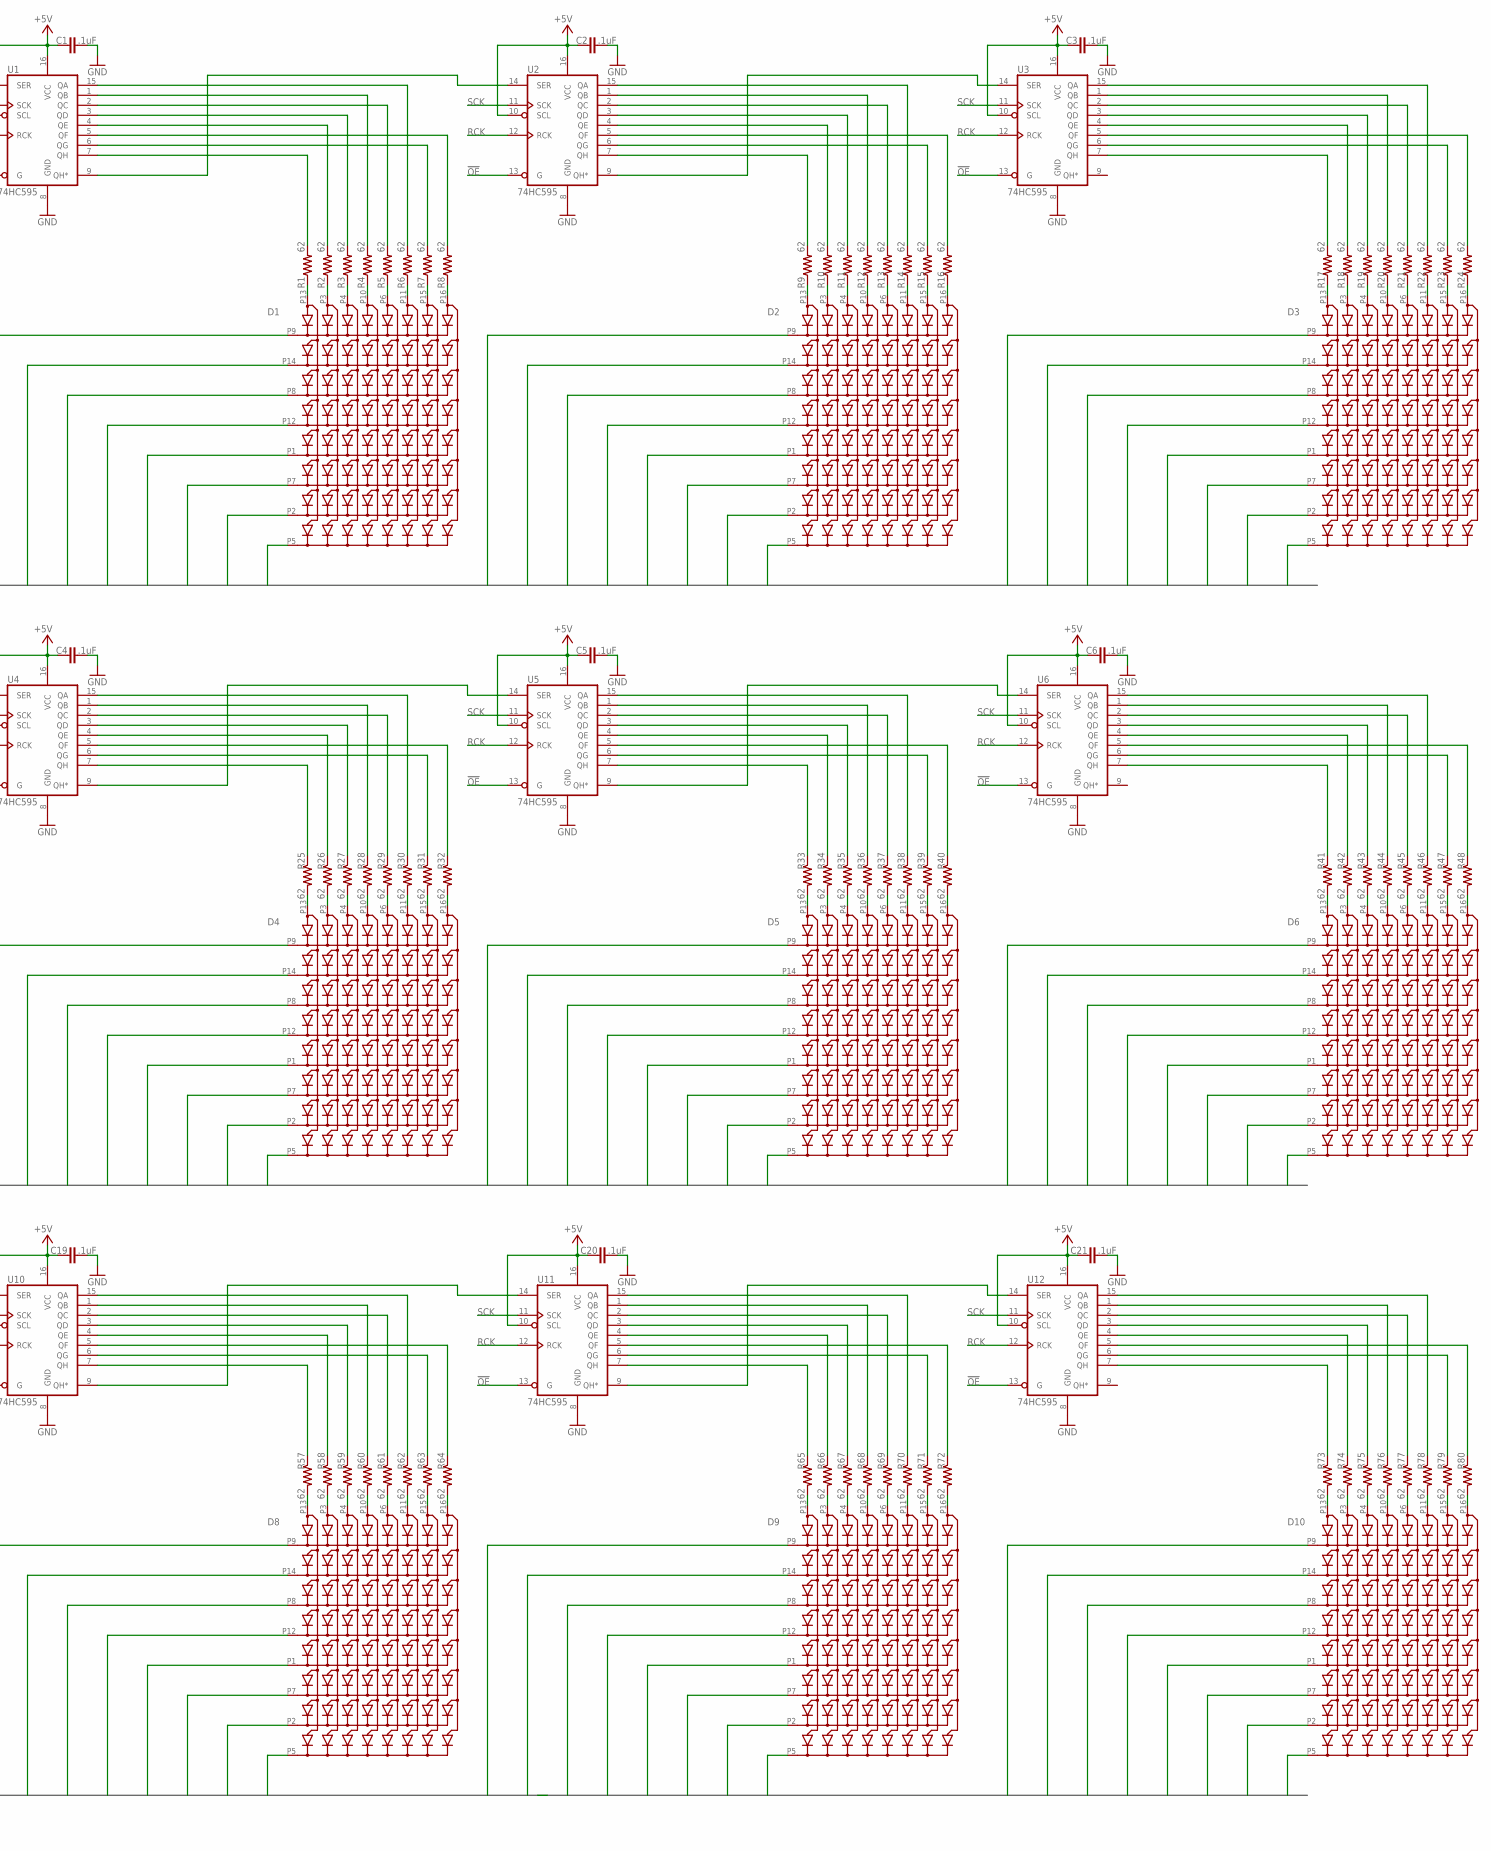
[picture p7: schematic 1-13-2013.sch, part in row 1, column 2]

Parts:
C1, C2, C3, C4, C5, C6, C7, C8, C9, C18, C19, C20, C21, C22, C23: .1uF; 0603/1608METRIC
C10, C11: 1uF; 0603/1608METRIC
C12, C13: 100uF; CAP-UWX-6.3
C14, C15: 100uF; CAP-UWX-6.3; MANPARTNO UWX1C101MCL1GB
C16, C17: 22pF; 0603/1608METRIC; VOLTAGE 25V
D1, D2, D3, D4, D5, D6, D8, D9, D10: WHITE; HS-2085BX
D7: TEPT4400; LED3MM
F1, F2, F3, F4: RUBBER-FOOT; SJ-5518
GND: HEADERPIN
J1: DC-BARREL-JACK-SWITCH; PJ-075DH-SMT-TR
J2: PROGHEADER-PINS; ATMEL-PROGRAMMING-HEADER
Q1, Q2, Q3, Q4, Q5, Q6, Q7, Q8: FDN335; SOT23
R1: 62; 0603/1608METRIC
R2, R3, R4, R5, R6, R7, R8, R9, R10, R11, R12, R13, R14, R15, R16, R17, R18, R19, R20, R21, R22, R23, R24, R25, R26, R27, R28, R29, R30, R31, R32, R33, R34, R35, R36, R37, R38, R39, R40, R41, R42, R43, R44, R45, R46, R47, R48, R57, R58, R59, R60, R61, R62, R63, R64, R65, R66, R67, R68, R69, R70, R71, R72, R73, R74, R75, R76, R77, R78, R79, R80: 62; 0603/1608METRIC; TOLERANCE 5%; MANPARTNO RC0603JR-0762RL
R49, R50, R52, R53, R56, R81, R82, R83: 2k; 0603/1608METRIC
R51: 47k; 0603/1608METRIC
R54: 10k; 0603/1608METRIC
R55: 4.7k; 0603/1608METRIC
RX: HEADERPIN
SW1, SW2: 4mm; PTS645SM43SMTRLFS; MANPARTNO PTS645SM43SMTR LFS
TX: HEADERPIN
U1, U2, U3, U4, U5, U6, U10, U11, U12: 74HC595; SO16
U7: ATMega328A; TQFP-32
U8: 74HC138; SO16
U9, U13: 74HC14; SO14
X1: 11.0592MHz; HC49UP; MANPARTNO 9C-11.0592MEEJ-T

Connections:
!OE: R54.P1 (1), U1.13 (G), U2.13 (G), U3.13 (G), U4.13 (G), U5.13 (G), U6.13 (G), U7.P10 (PD6(PCINT22/OC0A/AIN0)), U10.13 (G), U11.13 (G), U12.13 (G)
!RESET: J2.P5 (!RESET), R55.P1 (1), U7.P29 (PC6(RESET/PCINT14))
+5V: C1.P1 (1), C2.P1 (1), C3.P1 (1), C4.P1 (1), C5.P1 (1), C6.P1 (1), C7.P1 (1), C8.P1 (1), C10.P1 (1), C11.P1 (1), C12.+ (1), C13.+ (1), C14.+ (1), C15.+ (1), C18.P1 (1), C19.P1 (1), C20.P1 (1), C21.P1 (1), C22.P1 (1), C23.P1 (1), J1.1 (PIN), J2.P2 (VCC), R51.P2 (2), R54.P2 (2), R55.P2 (2), U1.10 (SCL), U1.16 (VCC), U2.10 (SCL), U2.16 (VCC), U3.10 (SCL), U3.16 (VCC), U4.10 (SCL), U4.16 (VCC), U5.10 (SCL), U5.16 (VCC), U6.10 (SCL), U6.16 (VCC), U7.P4 (VCC), U7.P6 (VCC2), U7.P18 (AVCC), U8.6 (G1), U8.16 (VCC), U9.14 (VCC), U10.10 (SCL), U10.16 (VCC), U11.10 (SCL), U11.16 (VCC), U12.10 (SCL), U12.16 (VCC), U13.14 (VCC)
GND: C1.P2 (2), C2.P2 (2), C3.P2 (2), C4.P2 (2), C5.P2 (2), C6.P2 (2), C7.P2 (2), C8.P2 (2), C9.P2 (2), C10.P2 (2), C11.P2 (2), C12.- (2), C13.- (2), C14.- (2), C15.- (2), C16.P2 (2), C17.P2 (2), C18.P2 (2), C19.P2 (2), C20.P2 (2), C21.P2 (2), C22.P2 (2), C23.P2 (2), D7.K (C), GND.P$1, J1.2 (BARREL), J2.P6 (GND), Q1.2 (S), Q2.2 (S), Q3.2 (S), Q4.2 (S), Q5.2 (S), Q6.2 (S), Q7.2 (S), Q8.2 (S), SW1.P3, SW1.P4, SW2.P3, SW2.P4, U1.8 (GND), U2.8 (GND), U3.8 (GND), U4.8 (GND), U5.8 (GND), U6.8 (GND), U7.P3 (GND), U7.P5 (GND2), U7.P21 (GND3), U8.4 (G2A), U8.5 (G2B), U8.8 (GND), U9.7 (GND), U9.11 (I), U9.13 (I), U10.8 (GND), U11.8 (GND), U12.8 (GND), U13.7 (GND), U13.11 (I), U13.13 (I)
MISO: J2.P1 (MISO), U7.P16 ((PCINT4/MISO)PB4)
MOSI: J2.P4 (MOSI), U7.P15 ((PCINT3/OC2A/MOSI)PB3)
unnamed: D1.P13 (C1), R1.P1 (1)
unnamed: R4.P2 (2), U1.1 (QB)
unnamed: D1.P3 (C2), R2.P1 (1)
unnamed: R5.P2 (2), U1.2 (QC)
unnamed: D1.P4 (C3), R3.P1 (1)
unnamed: R14.P2 (2), U2.15 (QA)
unnamed: D1.P10 (C4), R4.P1 (1)
unnamed: R13.P2 (2), U2.2 (QC)
unnamed: D1.P6 (C5), R5.P1 (1)
unnamed: R12.P2 (2), U2.1 (QB)
unnamed: D1.P11 (C6), R6.P1 (1)
unnamed: R11.P2 (2), U2.3 (QD)
unnamed: D1.P15 (C7), R7.P1 (1)
unnamed: R10.P2 (2), U2.4 (QE)
unnamed: D1.P16 (C8), R8.P1 (1)
unnamed: R16.P2 (2), U2.5 (QF)
unnamed: U8.15 (Y0), U9.9 (I)
unnamed: D2.P13 (C1), R9.P1 (1)
unnamed: R21.P2 (2), U3.2 (QC)
unnamed: D2.P3 (C2), R10.P1 (1)
unnamed: R20.P2 (2), U3.1 (QB)
unnamed: D2.P4 (C3), R11.P1 (1)
unnamed: R19.P2 (2), U3.3 (QD)
unnamed: D2.P10 (C4), R12.P1 (1)
unnamed: R18.P2 (2), U3.4 (QE)
unnamed: D2.P6 (C5), R13.P1 (1)
unnamed: R24.P2 (2), U3.5 (QF)
unnamed: D2.P11 (C6), R14.P1 (1)
unnamed: R32.P1 (1), U4.5 (QF)
unnamed: D2.P15 (C7), R15.P1 (1)
unnamed: R25.P1 (1), U4.7 (QH)
unnamed: D2.P16 (C8), R16.P1 (1)
unnamed: R52.P1 (1), U9.2 (O)
unnamed: R50.P1 (1), U9.6 (O)
unnamed: R49.P1 (1), U9.8 (O)
unnamed: R53.P1 (1), U9.4 (O)
unnamed: R83.P1 (1), U13.4 (O)
unnamed: R82.P1 (1), U13.2 (O)
unnamed: R81.P1 (1), U13.8 (O)
unnamed: R56.P1 (1), U13.6 (O)
unnamed: C17.P1 (1), U7.P7 ((PCINT6/XTAL1/TOSC1)PB6), X1.1
unnamed: R7.P2 (2), U1.6 (QG)
unnamed: TX.P$1, U7.P31 (PD1(TXD/PCINT17))
unnamed: C16.P1 (1), U7.P8 ((PCINT7/XTAL2/TOSC2)PB7), X1.2
unnamed: RX.P$1, U7.P30 (PD0(RXD/PCINT16))
unnamed: Q3.1 (G), R52.P2 (2)
unnamed: SW2.P2, U7.P24 (PC1(ADC1/PCINT9))
unnamed: SW1.P2, U7.P23 (PC0(ADC0/PCINT8))
unnamed: R1.P2 (2), U1.7 (QH)
unnamed: Q1.1 (G), R49.P2 (2)
unnamed: R8.P2 (2), U1.5 (QF)
unnamed: R2.P2 (2), U1.4 (QE)
unnamed: R3.P2 (2), U1.3 (QD)
unnamed: R31.P1 (1), U4.6 (QG)
unnamed: R26.P1 (1), U4.4 (QE)
unnamed: R6.P2 (2), U1.15 (QA)
unnamed: R27.P1 (1), U4.3 (QD)
unnamed: R29.P1 (1), U4.2 (QC)
unnamed: R30.P1 (1), U4.15 (QA)
unnamed: R33.P1 (1), U5.7 (QH)
unnamed: R39.P1 (1), U5.6 (QG)
unnamed: R40.P1 (1), U5.5 (QF)
unnamed: R34.P1 (1), U5.4 (QE)
unnamed: R35.P1 (1), U5.3 (QD)
unnamed: R36.P1 (1), U5.1 (QB)
unnamed: R37.P1 (1), U5.2 (QC)
unnamed: R38.P1 (1), U5.15 (QA)
unnamed: R41.P1 (1), U6.7 (QH)
unnamed: R47.P1 (1), U6.6 (QG)
unnamed: R46.P1 (1), U6.15 (QA)
unnamed: R45.P1 (1), U6.2 (QC)
unnamed: R44.P1 (1), U6.1 (QB)
unnamed: R43.P1 (1), U6.3 (QD)
unnamed: U8.14 (Y1), U9.5 (I)
unnamed: U4.9 (QH*), U5.14 (SER)
unnamed: U5.9 (QH*), U6.14 (SER)
unnamed: U8.13 (Y2), U9.1 (I)
unnamed: U1.9 (QH*), U2.14 (SER)
unnamed: U2.9 (QH*), U3.14 (SER)
unnamed: R42.P1 (1), U6.4 (QE)
unnamed: R48.P1 (1), U6.5 (QF)
unnamed: R57.P1 (1), U10.7 (QH)
unnamed: R63.P1 (1), U10.6 (QG)
unnamed: R64.P1 (1), U10.5 (QF)
unnamed: R58.P1 (1), U10.4 (QE)
unnamed: R59.P1 (1), U10.3 (QD)
unnamed: R15.P2 (2), U2.6 (QG)
unnamed: R61.P1 (1), U10.2 (QC)
unnamed: R60.P1 (1), U10.1 (QB)
unnamed: R62.P1 (1), U10.15 (QA)
unnamed: R65.P1 (1), U11.7 (QH)
unnamed: R71.P1 (1), U11.6 (QG)
unnamed: R72.P1 (1), U11.5 (QF)
unnamed: R66.P1 (1), U11.4 (QE)
unnamed: R67.P1 (1), U11.3 (QD)
unnamed: R69.P1 (1), U11.2 (QC)
unnamed: R9.P2 (2), U2.7 (QH)
unnamed: R68.P1 (1), U11.1 (QB)
unnamed: R70.P1 (1), U11.15 (QA)
unnamed: R73.P1 (1), U12.7 (QH)
unnamed: R79.P1 (1), U12.6 (QG)
unnamed: R80.P1 (1), U12.5 (QF)
unnamed: R74.P1 (1), U12.4 (QE)
unnamed: R75.P1 (1), U12.3 (QD)
unnamed: R77.P1 (1), U12.2 (QC)
unnamed: R76.P1 (1), U12.1 (QB)
unnamed: R78.P1 (1), U12.15 (QA)
unnamed: U10.9 (QH*), U11.14 (SER)
unnamed: U11.9 (QH*), U12.14 (SER)
unnamed: U8.12 (Y3), U9.3 (I)
unnamed: U8.11 (Y4), U13.5 (I)
unnamed: U8.10 (Y5), U13.9 (I)
unnamed: U8.9 (Y6), U13.1 (I)
unnamed: U8.7 (Y7), U13.3 (I)
unnamed: D7.A, R51.P1 (1), U7.P22 (ADC7)
unnamed: D3.P13 (C1), R17.P1 (1)
unnamed: D3.P3 (C2), R18.P1 (1)
unnamed: D3.P4 (C3), R19.P1 (1)
unnamed: D3.P10 (C4), R20.P1 (1)
unnamed: D3.P6 (C5), R21.P1 (1)
unnamed: D3.P11 (C6), R22.P1 (1)
unnamed: D3.P15 (C7), R23.P1 (1)
unnamed: D3.P16 (C8), R24.P1 (1)
unnamed: R17.P2 (2), U3.7 (QH)
unnamed: R23.P2 (2), U3.6 (QG)
unnamed: R22.P2 (2), U3.15 (QA)
unnamed: U7.P12 ((PCINT0/CLKO/ICP1)PB0), U8.3 (C)
unnamed: U7.P13 ((PCINT1/OC1A)PB1), U8.2 (B)
unnamed: U7.P14 ((PCINT2/SS/OC1B)PB2), U8.1 (A)
unnamed: C9.P1 (1), U7.P20 (AREF)
unnamed: D4.P13 (C1), R25.P2 (2)
unnamed: D4.P3 (C2), R26.P2 (2)
unnamed: D4.P4 (C3), R27.P2 (2)
unnamed: D4.P10 (C4), R28.P2 (2)
unnamed: D4.P6 (C5), R29.P2 (2)
unnamed: D4.P11 (C6), R30.P2 (2)
unnamed: D4.P15 (C7), R31.P2 (2)
unnamed: D4.P16 (C8), R32.P2 (2)
unnamed: R28.P1 (1), U4.1 (QB)
unnamed: Q7.1 (G), R82.P2 (2)
unnamed: Q2.1 (G), R50.P2 (2)
unnamed: Q4.1 (G), R53.P2 (2)
unnamed: Q5.1 (G), R56.P2 (2)
unnamed: Q6.1 (G), R81.P2 (2)
unnamed: Q8.1 (G), R83.P2 (2)
unnamed: D5.P13 (C1), R33.P2 (2)
unnamed: D5.P3 (C2), R34.P2 (2)
unnamed: D5.P4 (C3), R35.P2 (2)
unnamed: D5.P10 (C4), R36.P2 (2)
unnamed: D5.P6 (C5), R37.P2 (2)
unnamed: D5.P11 (C6), R38.P2 (2)
unnamed: D5.P15 (C7), R39.P2 (2)
unnamed: D5.P16 (C8), R40.P2 (2)
unnamed: D6.P13 (C1), R41.P2 (2)
unnamed: D6.P3 (C2), R42.P2 (2)
unnamed: D6.P4 (C3), R43.P2 (2)
unnamed: D6.P10 (C4), R44.P2 (2)
unnamed: D6.P6 (C5), R45.P2 (2)
unnamed: D6.P11 (C6), R46.P2 (2)
unnamed: D6.P15 (C7), R47.P2 (2)
unnamed: D6.P16 (C8), R48.P2 (2)
unnamed: D8.P13 (C1), R57.P2 (2)
unnamed: D8.P3 (C2), R58.P2 (2)
unnamed: D8.P4 (C3), R59.P2 (2)
unnamed: D8.P10 (C4), R60.P2 (2)
unnamed: D8.P6 (C5), R61.P2 (2)
unnamed: D8.P11 (C6), R62.P2 (2)
unnamed: D8.P15 (C7), R63.P2 (2)
unnamed: D8.P16 (C8), R64.P2 (2)
unnamed: D9.P13 (C1), R65.P2 (2)
unnamed: D9.P3 (C2), R66.P2 (2)
unnamed: D9.P4 (C3), R67.P2 (2)
unnamed: D9.P10 (C4), R68.P2 (2)
unnamed: D9.P6 (C5), R69.P2 (2)
unnamed: D9.P11 (C6), R70.P2 (2)
unnamed: D9.P15 (C7), R71.P2 (2)
unnamed: D9.P16 (C8), R72.P2 (2)
unnamed: D10.P13 (C1), R73.P2 (2)
unnamed: D10.P3 (C2), R74.P2 (2)
unnamed: D10.P4 (C3), R75.P2 (2)
unnamed: D10.P10 (C4), R76.P2 (2)
unnamed: D10.P6 (C5), R77.P2 (2)
unnamed: D10.P11 (C6), R78.P2 (2)
unnamed: D10.P15 (C7), R79.P2 (2)
unnamed: D10.P16 (C8), R80.P2 (2)
PSCK: J2.P3 (SCK), U7.P17 ((SCK/PCINT5)PB5)
RCK: U1.12 (RCK), U2.12 (RCK), U3.12 (RCK), U4.12 (RCK), U5.12 (RCK), U6.12 (RCK), U7.P25 (PC2(ADC2/PCINT10)), U10.12 (RCK), U11.12 (RCK), U12.12 (RCK)
ROW0: D1.P9 (R1), D2.P9 (R1), D3.P9 (R1), D4.P9 (R1), D5.P9 (R1), D6.P9 (R1), D8.P9 (R1), D9.P9 (R1), D10.P9 (R1), Q1.3 (D)
ROW1: D1.P14 (R2), D2.P14 (R2), D3.P14 (R2), D4.P14 (R2), D5.P14 (R2), D6.P14 (R2), D8.P14 (R2), D9.P14 (R2), D10.P14 (R2), Q2.3 (D)
ROW2: D1.P8 (R3), D2.P8 (R3), D3.P8 (R3), D4.P8 (R3), D5.P8 (R3), D6.P8 (R3), D8.P8 (R3), D9.P8 (R3), D10.P8 (R3), Q3.3 (D)
ROW3: D1.P12 (R4), D2.P12 (R4), D3.P12 (R4), D4.P12 (R4), D5.P12 (R4), D6.P12 (R4), D8.P12 (R4), D9.P12 (R4), D10.P12 (R4), Q4.3 (D)
ROW4: D1.P1 (R5), D2.P1 (R5), D3.P1 (R5), D4.P1 (R5), D5.P1 (R5), D6.P1 (R5), D8.P1 (R5), D9.P1 (R5), D10.P1 (R5), Q5.3 (D)
ROW5: D1.P7 (R6), D2.P7 (R6), D3.P7 (R6), D4.P7 (R6), D5.P7 (R6), D6.P7 (R6), D8.P7 (R6), D9.P7 (R6), D10.P7 (R6), Q6.3 (D)
ROW6: D1.P2 (R7), D2.P2 (R7), D3.P2 (R7), D4.P2 (R7), D5.P2 (R7), D6.P2 (R7), D8.P2 (R7), D9.P2 (R7), D10.P2 (R7), Q7.3 (D)
ROW7: D1.P5 (R8), D2.P5 (R8), D3.P5 (R8), D4.P5 (R8), D5.P5 (R8), D6.P5 (R8), D8.P5 (R8), D9.P5 (R8), D10.P5 (R8), Q8.3 (D)
SCK: U1.11 (SCK), U2.11 (SCK), U3.11 (SCK), U4.11 (SCK), U5.11 (SCK), U6.11 (SCK), U7.P32 (PD2(INT0/PCINT18)), U10.11 (SCK), U11.11 (SCK), U12.11 (SCK)
SDATA1: U1.14 (SER), U7.P27 (PC4(ADC4/SDA/PCINT12))
SDATA2: U4.14 (SER), U7.P26 (PC3(ADC3/PCINT11))
SDATA3: U7.P28 (PC5(ADC5/SCL/PCINT13)), U10.14 (SER)

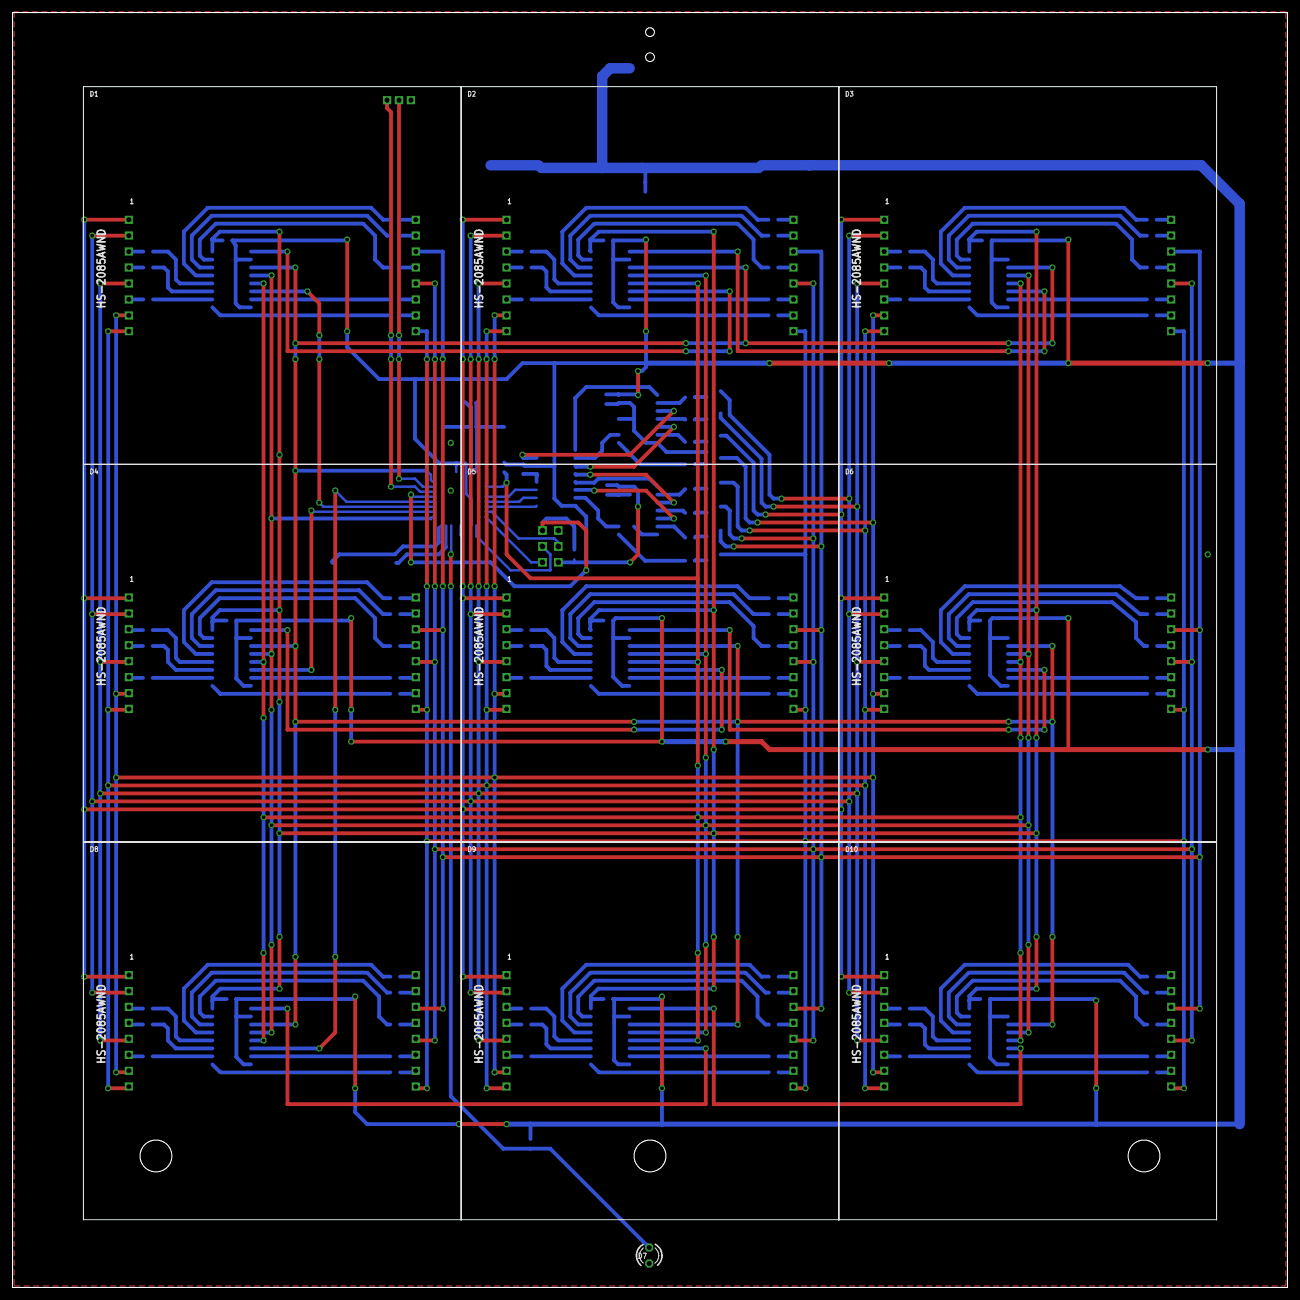
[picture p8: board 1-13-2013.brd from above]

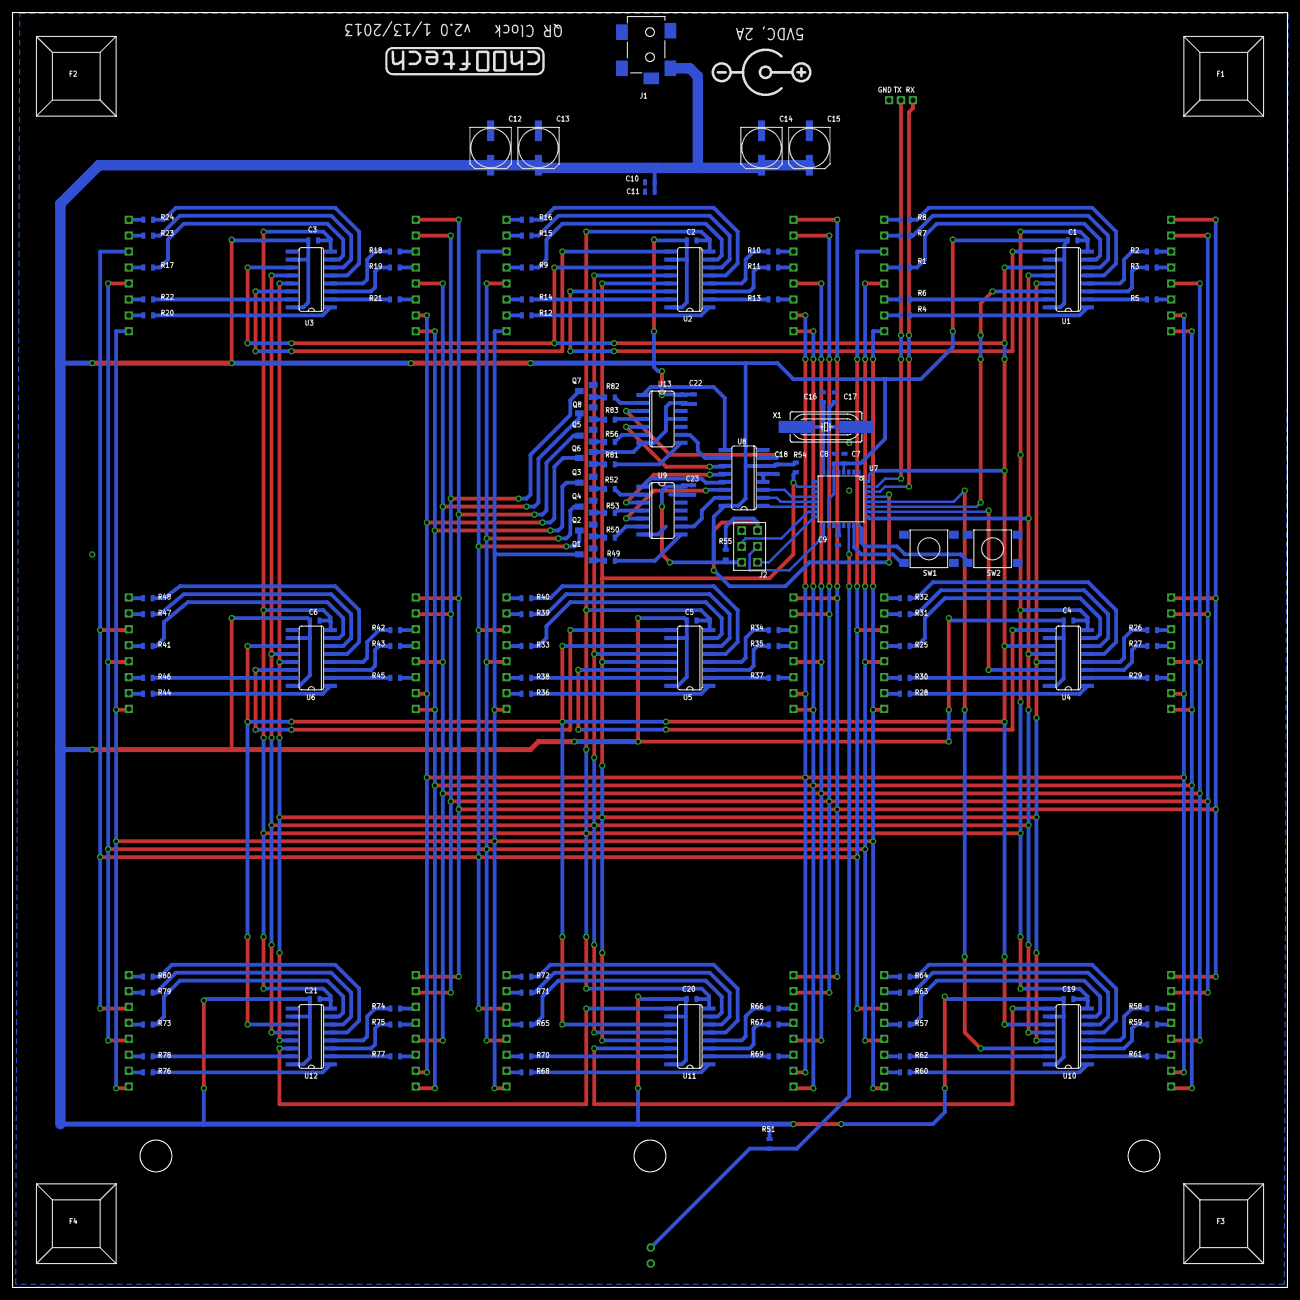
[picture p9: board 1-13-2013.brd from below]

Board: 2 copper layers, 203.2 x 203.2 mm, 149 parts (139 on the bottom side), 205 nets.

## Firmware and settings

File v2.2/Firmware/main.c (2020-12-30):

//Firmware for QR clock 2.1


#include <avr/io.h>
#include <util/delay.h>
#include <avr/interrupt.h>
#include <avr/pgmspace.h>


uint8_t masterimage[72] = {0,0,0,0,0,0,0,0,0,0,0,0,0,0,0,0,0,0,0,0,0,0,0,0,0,0,0,0,0,0,0,0,0,0,0,0,0,0,0,0,0,0,0,0,0,0,0,0,0,0,0,0,0,0,0,0,0,0,0,0,0,0,0,0,0,0,0,0,0,0,0,0};

// tells the device to update the time
volatile uint8_t updatetime = 1;

#define timeSetTimeout 20

//count down until when you leave setting mode in seconds
volatile uint8_t timesettingcountdown = 0;

//time of day (in seconds since midnight)
volatile uint32_t time = 0;

//sets whether automatic brightness setting is enabled
volatile uint8_t autobrightness = 1;

//user set brightness value
volatile uint8_t manualBrightness=0;

//stores which column is currently being displayed
uint8_t col = 0;

//current setting for unused border
#define black 0
#define white 1
#define ticker 2
volatile uint8_t bordermode = ticker;

//current setting (seconds or just minutes?)
#define minutehand 0
#define secondhand 1
volatile uint8_t timemode = minutehand;

//returns a single bit value (true or false) from an array
uint8_t getbit(uint8_t * array, uint16_t pointer)
{
    return ((array[pointer/8])&(1<<(pointer%8)));
}

//sets a particular bit in a byte and returns the byte
uint8_t addpixel(uint8_t byte, uint8_t location)
{
    return byte|(1<<location);
}

//debugging routines
void yellowup()
{
    PORTD = PORTD | 1;
}

void yellowdown()
{

    PORTD = PORTD & 0XFE;

}
void greenup()
{
    PORTD = PORTD | 2;
    
}

void greendown()
{
    PORTD = PORTD & 0XFD;
}


/************************************************************************
 BEGIN CODE BLATANTLY COPIED FROM DEMO
 ************************************************************************/

//these two arrays store the log antilog values required for generating code words

const uint8_t alpha2int[256] PROGMEM =	{1,2,4,8,16,32,64,128,29,58,116,232,205,135,19,38,76,152,45,90,\
    180,117,234,201,143,3,6,12,24,48,96,192,157,39,78,156,37,74,148,\
    53,106,212,181,119,238,193,159,35,70,140,5,10,20,40,80,160,93,186,\
    105,210,185,111,222,161,95,190,97,194,153,47,94,188,101,202,137,15,\
    30,60,120,240,253,231,211,187,107,214,177,127,254,225,223,163,91,\
    182,113,226,217,175,67,134,17,34,68,136,13,26,52,104,208,189,103,\
    206,129,31,62,124,248,237,199,147,59,118,236,197,151,51,102,204,\
    133,23,46,92,184,109,218,169,79,158,33,66,132,21,42,84,168,77,154,\
    41,82,164,85,170,73,146,57,114,228,213,183,115,230,209,191,99,198,\
    145,63,126,252,229,215,179,123,246,241,255,227,219,171,75,150,49,\
    98,196,149,55,110,220,165,87,174,65,130,25,50,100,200,141,7,14,28,\
    56,112,224,221,167,83,166,81,162,89,178,121,242,249,239,195,155,43,\
    86,172,69,138,9,18,36,72,144,61,122,244,245,247,243,251,235,203,\
    139,11,22,44,88,176,125,250,233,207,131,27,54,108,216,173,71,142,1};

const uint8_t int2alpha[256] PROGMEM = {0,0,1,25,2,50,26,198,3,223,51,238,27,104,199,75,4,100,224,14,52,141,\
    239,129,28,193,105,248,200,8,76,113,5,138,101,47,225,36,15,33,53,147,\
    142,218,240,18,130,69,29,181,194,125,106,39,249,185,201,154,9,120,77,\
    228,114,166,6,191,139,98,102,221,48,253,226,152,37,179,16,145,34,136,\
    54,208,148,206,143,150,219,189,241,210,19,92,131,56,70,64,30,66,182,\
    163,195,72,126,110,107,58,40,84,250,133,186,61,202,94,155,159,10,21,\
    121,43,78,212,229,172,115,243,167,87,7,112,192,247,140,128,99,13,103,\
    74,222,237,49,197,254,24,227,165,153,119,38,184,180,124,17,68,146,217,\
    35,32,137,46,55,63,209,91,149,188,207,205,144,135,151,178,220,252,190,97,\
    242,86,211,171,20,42,93,158,132,60,57,83,71,109,65,162,31,45,67,216,183,\
    123,164,118,196,23,73,236,127,12,111,246,108,161,59,82,41,157,85,170,251,\
    96,134,177,187,204,62,90,203,89,95,176,156,169,160,81,11,245,22,235,122,\
    117,44,215,79,174,213,233,230,231,173,232,116,214,244,234,168,80,88,175};

//this array helps to untangle the column mapping of the shift registers' output.
//The input is a grid column 0 through 7, and the output is the corresponding column
//to output on such a column on the actual display.  This takes into account the
//re-ordering of pins to enable a cleaner layout.
const uint8_t col2col[8] PROGMEM = {2,1,7,5,6,4,3,0};



void arraycopy(uint8_t * from,uint8_t * to, uint8_t len)
{
    while(len)
    {
        to[len]=from[len];
        len--;
    }
}



//returns score from penalty 1 (consecutive blocks of color)
unsigned int penalty1(unsigned char * array)
{

	unsigned int scorex=0;
	unsigned int scorey=0;
	unsigned int i;
	unsigned int j;
	
	//keep track of the current color in the "run"
	char currentcolorx =0;
	char currentcolory=0;
	
	//keep track of current number of elements in a row
	char currentcountx = 0;
	char currentcounty = 0;
	
	
	
	for (i=0;i<21;i++)
	{
		for (j=0;j<21;j++)
		{
            //horizontal check
			//if the current pixel is the same color as the last one
			if (((getbit(&array[0], ((21*i)+j))==0) && (currentcolorx==0))||((getbit(&array[0], ((21*i)+j))!=0) && (currentcolorx!=0)))
			{
				currentcountx++;
                
                //if this is the fifth same color in a row, add 3 to the score
				if (currentcountx==5)
				{
					scorex+=3;
				}
                
                //for every one after 5, add one to the score
				if (currentcountx>5)
				{
					scorex+=1;
				}
				
			}
			else
			{
                //if the new color is different, toggle "currentcolor"
				currentcountx=1;
				if (currentcolorx)
					currentcolorx=0;
				else
					currentcolorx=1;
			}
            
            //vertical check
			//if the current pixel is the same color as the last one
			if (((getbit(&array[0], ((21*j)+i))==0) && (currentcolory==0))||((getbit(&array[0], ((21*j)+i))!=0) && (currentcolory!=0)))
			{
				currentcounty++;
                
                //if this is the fifth same color in a row, add 3 to the score
				if (currentcounty==5)
				{
					scorey+=3;
				}
                
                //for every one after 5, add one to the score
				if (currentcounty>5)
				{
					scorey+=1;
				}
			}
			else
			{
                //if the new color is different, toggle "currentcolor"
				currentcounty=1;
				if (currentcolory)
					currentcolory=0;
				else
					currentcolory=1;
			}
		}
		currentcountx=0;
		currentcounty=0;
	}
	return scorey+scorex;
}

//returns score from penalty 2 (2x2 blocks of same color)
unsigned int penalty2(unsigned char * array)
{
   
	unsigned int i;
	unsigned int j;
	unsigned int score=0;
	for (i=0;i<20;i++)
	{
		for (j=0;j<20;j++)
		{
			//printf("%s","X: ");
			//printf("%d",j);
			//printf("%s"," Y: ");
			//printf("%d",i);
			if ((getbit(&array[0],((21*i)+j)))&&(getbit(&array[0],((21*(i+1))+j)))&&(getbit(&array[0],((21*i)+j+1)))&&(getbit(&array[0],((21*(i+1))+j+1))))
			{
				score+=3;
                //	printf("%s","BING");
			}
			//printf("%s","\n");
			if (!(getbit(&array[0],((21*i)+j)))&&!(getbit(&array[0],((21*(i+1))+j)))&&!(getbit(&array[0],((21*i)+j+1)))&&!(getbit(&array[0],((21*(i+1))+j+1))))
				score+=3;
		}
	}

	return score;
}

//returns score from penalty 3 (blocks that look like positioning boxes)
unsigned int penalty3(unsigned char * array)
{
    
	unsigned int i;
	unsigned int j;
	unsigned int score=0;
	
	for(i=0;i<21;i++)
	{
		for (j=0;j<21;j++)
		{
            //These will keep track of how far through the patterns you have stepped
			char patternplace1x = 0;
            char patternplace1y = 0;
            char patternplace2x = 0;
            char patternplace2y = 0;
            for (j=0;j<21;j++)
            {
                //checking for "█ ███ █    "
                uint16_t pattern = 1954;
                
                //minor optimization: stop looking for the pattern if there's no more room on the line
                if ((21-j)>=(11-patternplace1x))
                {
                    //check to see if current pixel matches prototype pattern pixel
                    //if it does, increment the pattern pixel
                    if ((getbit(&array[0],(21*(i))+j) == ((pattern>>patternplace1x)&1)))
                        patternplace1x++;
                    else
                    {
                        //special case with pattern that looks like this
                        //"█ █ ███ █    "
                        if (patternplace1x==3)
                        {
                            patternplace1x=2;
                        }
                        else
                            //current pixel is not in pattern. Reset pattern.
                            patternplace1x=0;
                    }
                    
                    //if you've stepped all the way through the pattern
                    //increment the score
                    if (patternplace1x >= 11)
                    {
                        score+=40;
                        patternplace1x = 0;
                        
                    }
                }
                
                //minor optimization: stop looking for the pattern if there's no more room on the line
                if ((21-j)>=(11-patternplace1y))
                {
                    //check to see if current pixel matches prototype pattern pixel
                    //if it does, increment the pattern pixel
                    if ((getbit(&array[0],(21*(j))+i) == ((pattern>>patternplace1y)&1)))
                        patternplace1y++;
                    else
                    {
                        //special case with pattern that looks like this
                        //"█ █ ███ █    "
                        if (patternplace1y==3)
                        {
                            patternplace1y=2;
                        }
                        else
                            //current pixel is not in pattern. Reset pattern.
                            patternplace1y=0;
                    }
                    //if you've stepped all the way through the pattern
                    //increment the score
                    if (patternplace1y >= 11)
                    {
                        score+=40;
                        patternplace1y = 0;
                    }
                }
                
                //checking for "    █ ███ █"
                uint16_t pattern2 = 559;
                
                //minor optimization: stop looking for the pattern if there's no more room on the line
                if ((21-j)>=(11-patternplace2x))
                {
                    //check to see if current pixel matches prototype pattern pixel
                    //if it does, increment the pattern pixel
                    if ((getbit(&array[0],(21*(i))+j) == ((pattern2>>patternplace2x)&1)))
                        patternplace2x++;
                    else
                    {
                        //this handles a special case and accommodates an arbitrary amount of whitespace before the pattern.
                        //i.e. if you got 4 whites in a row, don't quit when you get another
                        if ((patternplace2x==4)&&(getbit(&array[0],(21*(i))+j)))
                        {}
                        else
                            patternplace2x=0;
                    }
                    if (patternplace2x >= 11)
                    {
                        score+=40;
                        patternplace2x = 0;
                        
                    }
                }

                //minor optimization: stop looking for the pattern if there's no more room on the line
                if ((21-j)>=(11-patternplace2y))
                {
                    //check to see if current pixel matches prototype pattern pixel
                    //if it does, increment the pattern pixel
                    if ((getbit(&array[0],(21*(j))+i) == ((pattern2>>patternplace2y)&1)))
                        patternplace2y++;
                    else
                    {
                        //this handles a special case and accommodates an arbitrary amount of whitespace before the pattern.
                        //i.e. if you got 4 whites in a row, don't quit when you get another
                        if ((patternplace2y==4)&&(getbit(&array[0],(21*(j))+i)))
                        {}
                        else
                            patternplace2y=0;
                        
                    }
                    if (patternplace2y >= 11)
                    {
                        score+=40;
                        patternplace2y = 0;
                        
                    }
                }
            }
        }
	}
	return score;
}


//calculates the penalty which has to do with how balanced the white and dark pixels are.
unsigned int penalty4(unsigned char * array)
{
    
	unsigned int whitecount=0;
	unsigned int score=0;
	
    
    uint8_t i;
	uint8_t j;
	
    //if we're just keeping count, there's really no need to follow the structure of the
    //LED matrix.  We can just measure the bits directly.
	for (i=0;i<55;i++)
    {
        uint8_t temp = array[i];
        for (j=0;j<8;j++)
        {
            //step through the bits
            if ((temp>>j)&1)
                whitecount++;
        }
    }
    
    //get that 441st bit
    if (array[56]&1)
        whitecount++;
    
    score = ((whitecount*100)/441);
    
    //a "perfect score" is 50.  This part calculates how far off you are from 50.
	if (score>=50)
		score-=50;
	else if (score<50)
		score=49-score; //the 49 is to simulate the truncation that would have happened if I was using floating point.
	score*=2;
	return score;
}


//used to help convert ascii characters into QR code characters.  Only useful
//in C code written for command line.  Now it simply returns what you pass to it.
unsigned int asciiconvert(char asciichar)
{
    return asciichar;
    
	if (asciichar >=48 && asciichar <=57) //character is a number
		return asciichar-48;
	else if(asciichar >=65 && asciichar<=90) //character is a letter
		return asciichar-55;
	else if(asciichar == 32) //space
		return 36;
	else if(asciichar == 36)//$
		return 37;
	else if(asciichar == 37)//%
		return 38;
	else if(asciichar == 42)//*
		return 39;
	else if(asciichar == 43)//+
		return 40;
	else if(asciichar == 45)//-
		return 41;
	else if(asciichar == 46)//.
		return 42;
	else if(asciichar == 47)// /
		return 43;
	else if(asciichar == 58)//:
		return 44;
	else return 36; //return a space by default.
}


//returns the location of the first nonzero element in the array (assuming array 13 elements long)
unsigned char firstnonzero(unsigned char * array)
{
	unsigned char i=13;
	
	while (array[i]==0 && i>0)
	{
		i--;
	}
	return i;
}

//this function adds a bit to an array of chars working left-justified.
//it adds the bit at the location specified by the "pointer" pointer
void addbit(unsigned char * array, int * pointer, char bit)
{
	uint8_t bytenum = *pointer/8;
	uint8_t bitnum = *pointer%8;
	if (bit==1)
	{
		array[bytenum] = array[bytenum]|(1<<bitnum);
	}
	else
	{
		array[bytenum] = array[bytenum]&(~(1<<bitnum));
	}
}

//this function adds multiple bits to an array of chars.
//it works just like addbit, but it will add "length" many bits.
//note, if length isn't set right, it could truncate your bits.
void addbits(unsigned char * array, int * pointer, int bits, char length)
{
	length--;
	char i;
	for (i=length;i>=0;i--)
	{
		addbit(array,pointer,(((1<<i)&bits)>>i));
		*pointer=*pointer-1;
	}
}
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
int main(void)
{
    DDRD = 0XFF;
    DDRB = 0XFF;
    DDRC = 0xFC; //input for switches on PC0, PC1
    PORTC = 3; //internal pullups active
    
    //enable PCinterrupts for buttons
    PCICR = 0x02; //enable pin change interrupts for [14:8]
    PCMSK1 = 0x03; //enable PCINT8-9 for buttons
    
    
    
    //timer2 is used to refresh the display
    TCCR2A = 0X02;  //compare match (mode 2)
    TCCR2B = 0x04;  //compare match (mode 2) mode, clock scaler /64
    TIMSK2 = 0x02;  //compare match enable
    OCR2A = 0x58;   //determines refresh rate.  The lower, the faster.
    
    //timer0 is used to control brightness
    TCCR0A = 0xC3;  //set on compare match, clear on bottom. Fast PWM mode.
    TCCR0B = 1; //no prescaling.
    OCR0A = 40;
    
    //timer1 keeps real time
    TCCR1A = 0x00; //Mode 4: CTC interrupt on compare match
    TCCR1B = 0x0D; //clk/1024=>10.8kHz interrupt with 11.0592MHz crystal CTC interrupt on compare match
    TIMSK1 = 2; //enable compare match A on timer 1
    OCR1A = 10800; //overflow once per second
    TCNT1 = 0;
    sei();
    
    ADCSRA = 0X84;  //ADC Enable
    ADMUX = 0X67;   //Use ADC7, Left adjust result.  Use AVCC as reference.
    
    
    //animate startup
    whiteout();
    
    //set initial brightness
    ADCSRA|=0b01000000; //START CONVERSION
    while((ADCSRA & (0b01000000))) //Is the ADC done?
    {}
    convertbrightness();
    
    
    //ascii array that will contain text to be QRified
    uint8_t input[16]={0};
    char length = 1;
    
    //matrix used to drive the display during time setting
    uint8_t timesetmatrix[56]={0,0,0,0,0,0,0,0,0,0,0,0,0,0,0,0,0,0,0,0,0,0,0,0,0,0,0,0,0,0,0,0,0,0,0,0,0,0,0,0,0,0,0,0,0,0,0,0,0,0,0,0,0,0,0,0};
    int timesetpointer=0;
    
    while(1)
    {
        timesettingcountdown = timeSetTimeout;
        //clearMatrix(&timesetmatrix[0]);
        while (timesettingcountdown)
        {
            //user pushed button
            if (!(PINC&1))
            {
                _delay_ms(50);
                
                //if they let go, increment seconds
                if ((PINC&1))
                {
                    incminute();
                    TCNT1=0;//reset ticker;
                    resetSeconds();
                }
                //if they held on, change border mode
                else
                {
                    bordermode++;
                    bordermode=bordermode%3;
                    while (!(PINC&1))
                    {}
                    resetSeconds();
                }
            }
            
            //user pushed button
            if (!(PINC&2))
            {
                _delay_ms(50);
                
                //if they leg to, increment seconds
                if ((PINC&2))
                {
                    inchour();
                    TCNT1 = 0;//reset ticker;
                    resetSeconds();
                }
                //if they held on, change border mode
                else
                {
                    if (timemode==secondhand)
                        timemode = minutehand;
                    else
                        timemode = secondhand;
                    while (!(PINC&2))
                    {}
                    resetSeconds();
                }
                
            }
            
            
            //generate ascii array from current time
            length=updatetimeasciiarray(&input);
            uint8_t i;
            for (i=0;i<length;i++)
            {
                
                if ((input[i]!=25)&&(input[i]!=22)&&(input[i]!=10)&&(input[i]!=44))//only display numbers
                {
                    timesetpointer=input[i]+(21*i);
                    addbit(&timesetmatrix[0],&timesetpointer,1);
                }
                if ((input[i]==25))//add a dot for PM
                {
                    timesetpointer=(21*i);
                    addbit(&timesetmatrix[0],&timesetpointer,1);
                }
            }
            printmasterimage(&timesetmatrix);
            int k;
            for (k=0;k<56;k++)
            {
                timesetmatrix[k]=0; //clear off matrix
            }
            
        }


        
        
        length = updatetimeasciiarray(&input);//generate QR for the current minute
        createQR(&input,length);
        
        //Because the QR code is generated, held, and then displayed at the end of a tick,
        //advance the time here to give the generator a head start and let it catch up with realtime.
        //if you're in minutehand mode, you have plenty of time to generate the QR code for the current minute.
        if (timemode==secondhand)
            incsecond();
        
        
    
        //keep showing the time until someone presses a button and takes you out of time set mode.
        while (timesettingcountdown==0)
        {
            
            
            
            length = updatetimeasciiarray(&input[0]);
            
            
            createQR(&input[0],length);
            
            
            
        }
        
        
    }
    return 0;   /* never reached */
}
//refresh display
ISR(TIMER2_COMPA_vect)
{

    //limits how often the brightness is adjusted
    static uint8_t brightnessTimer=8;

    
    
    
    if (col<7)
    {
        col++;
    }
    else
    {
        //only update brightness at the end of a refresh

        //assume ADC is done
        brightnessTimer++;;
        if (brightnessTimer%8==0)
        {
            if (autobrightness)
                OCR0A = convertbrightness();
            else
                OCR0A = manualBrightness;
            

        }
        
        
        col=0;
    }
    displayenable(0);

    printrow(&masterimage[col*9]);
    
    setcol(col);
    storageclock();

    displayenable(1);

    
    
}


ISR(TIMER1_COMPA_vect)
{
    
    if (timesettingcountdown)
        timesettingcountdown--;

    if (!timesettingcountdown)
        updatetime=1;
    incsecond();

    
    
    
}

    
ISR (PCINT1_vect)
{
    timesettingcountdown = timeSetTimeout;
    updatetime=1;
}
